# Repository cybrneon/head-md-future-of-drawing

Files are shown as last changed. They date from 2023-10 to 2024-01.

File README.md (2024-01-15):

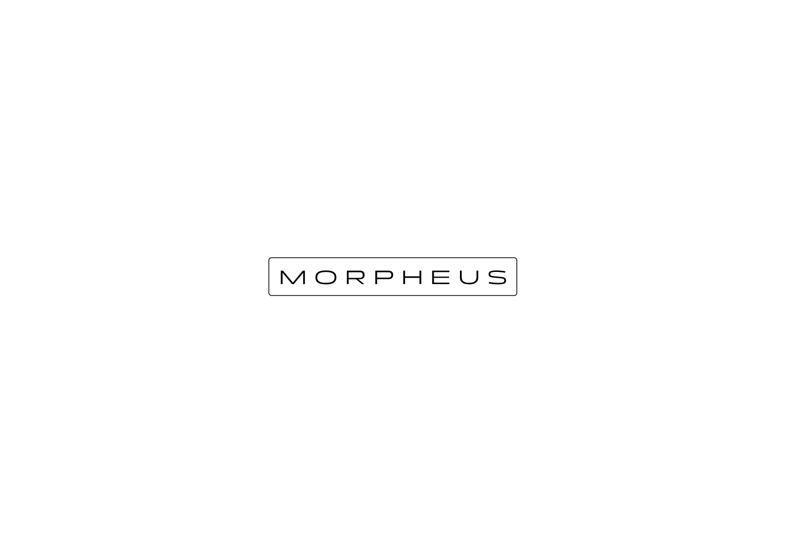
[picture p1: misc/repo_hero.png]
Project Morpheus


# Project Morpheus
Introducing, Morpheus. Your new, AI-enabled, narrator and guide to a new world of unlimited possibilities.

This project is the result of a semester workshop on drawing at the Master [Media Design](https://www.hesge.ch/head/en/programs-research/master-arts-media-design), [HEAD-Genève](https://www.hesge.ch/head/formations-recherche/master-en-media-design) in collaboration with [Caran D'Ache](https://www.carandache.com/ch/en)
<br>
With Alexia Mathieu, Douglas Edric Stanley, Laure Krayenbühl, Pierre Rossel and Pablo Bellon.

## Keywords
drawing, writing, drawing tools, writing tools, artificial intelligence, interaction design, storytelling objects, novel interactions, playable objects

### [**Process**](/process/)
Checkout the whole process for the project from the early beginnings to the end.

### [**Form**](/form/)
Design of the object's shape with 3d files.

### [**Electronics**](/electronics/)
Beep beep boo boo boop with Fritzing schematics.

### [**Presentations**](/presentations/)
Presentations from the concept to the final presentation.

### [**Software**](/software/)
Morpheus's Python script and files + tutorial on how to set up RPI.

### [**Story**](/story/)
One Story, its parameters and AI Output.

## Thanks
Thanks to the teacher's dedication, help and motivation throughout the project.

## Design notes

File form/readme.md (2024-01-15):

# Form

> [!INFO]
> Last Update: 2023-12-27 at 6:50pm

## 3D model
Here you will find my [Fusion 360 file.](/form/source/projectmorpheus_id.f3d)
And my STLs [here](/form/source/print).

## Snapshots
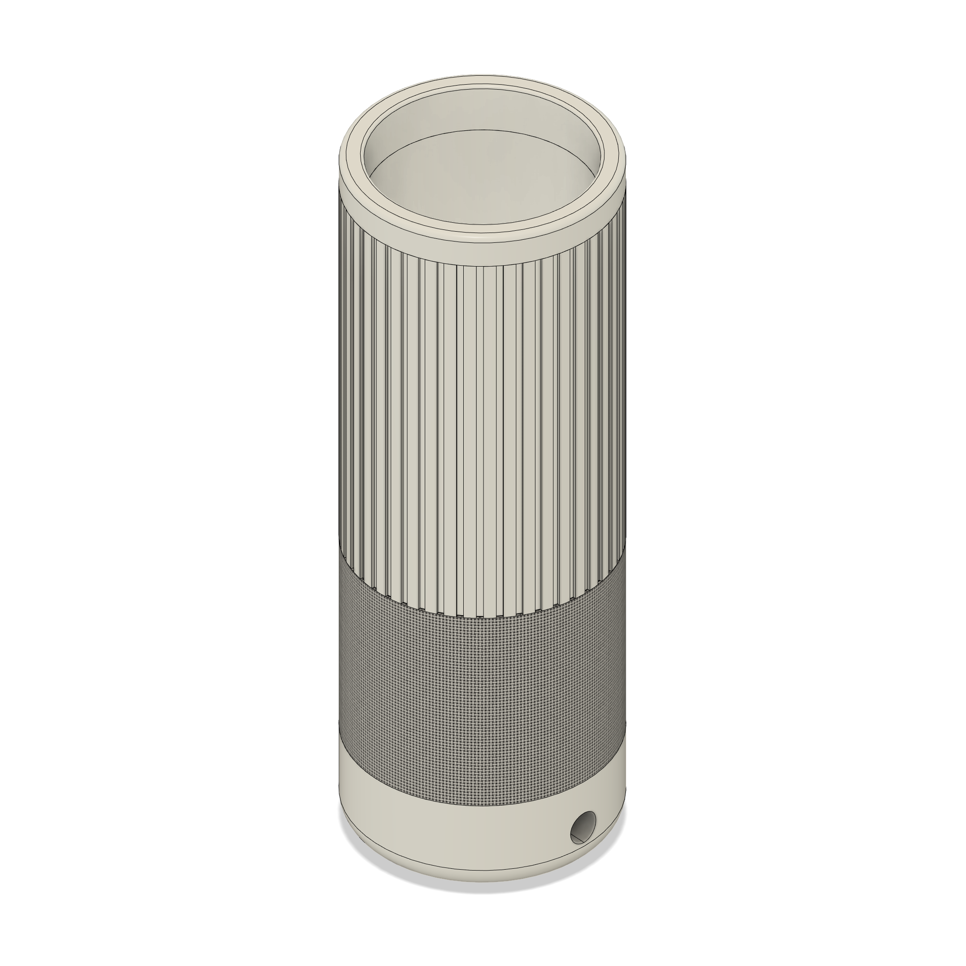
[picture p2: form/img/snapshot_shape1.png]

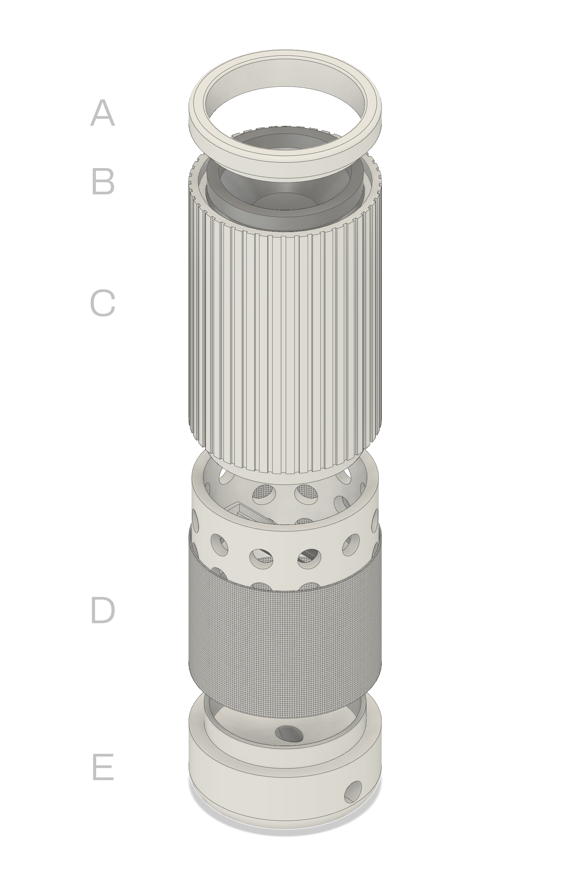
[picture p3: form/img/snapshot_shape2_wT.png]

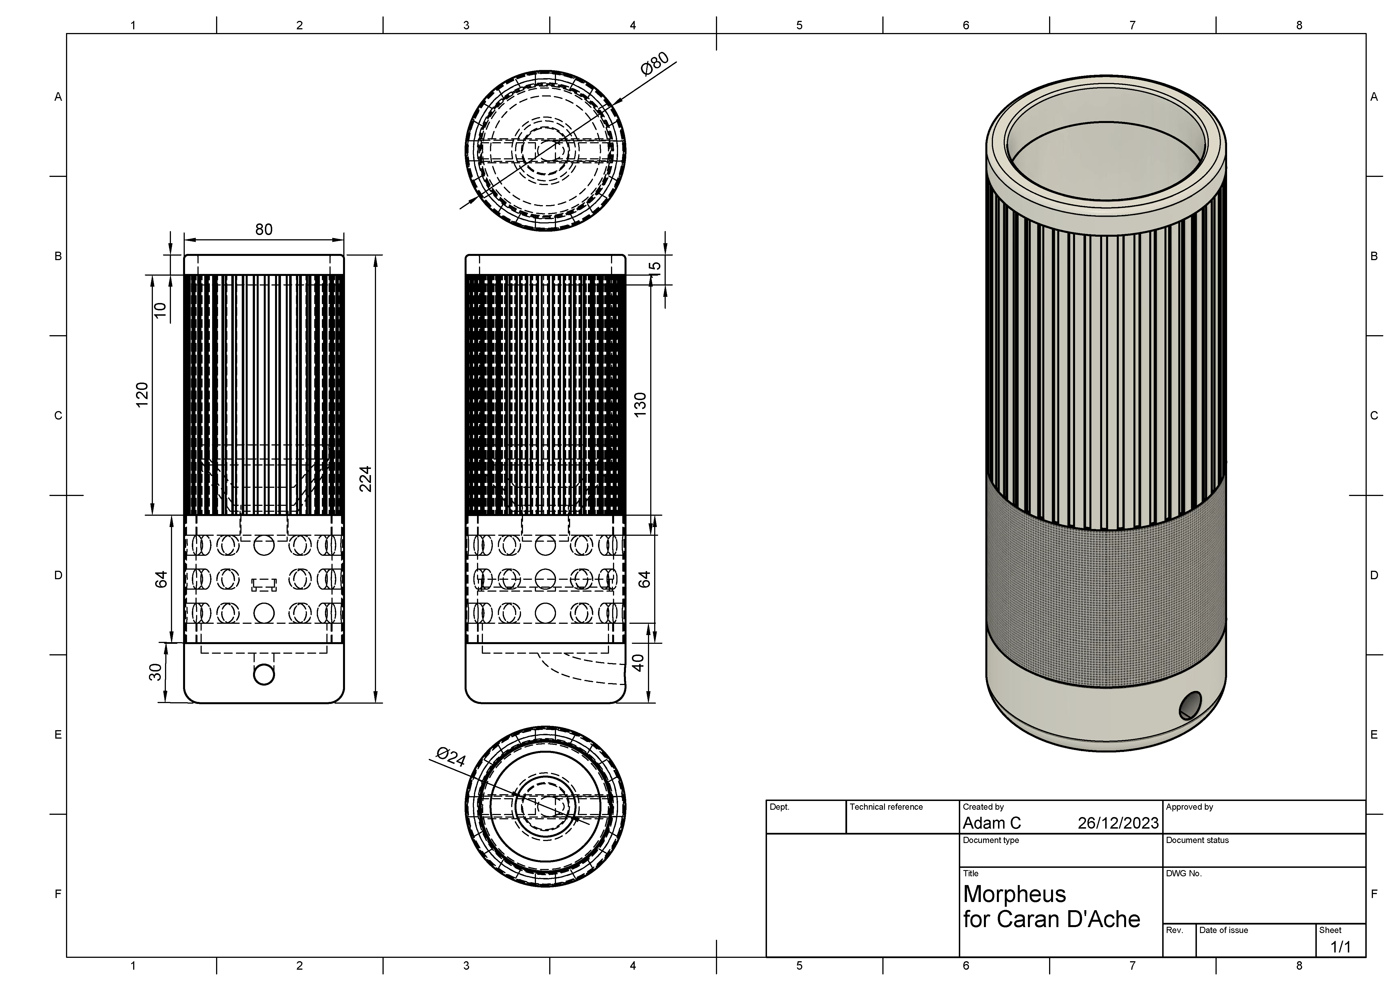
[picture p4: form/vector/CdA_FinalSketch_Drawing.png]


## Parts
A. Top Cover
<br>
B. Pen Trap Detector
<br>
C. Pen Holder Cylinder
<br>
D. Speaker Cage (Hidden, covered by fabrics)
<br>
E. Support Base

## Materials used
3D Printing for all parts (Atelier Prototypage).
<br>
The speaker cage is covered by fabrics (Linen).

## Dimensions
<b>The size of the whole structure is 220×80×80mm (H × W × L) </b>
<br>
A. 10 × 80 × 80 mm
<br>
C. 120 × 80 × 80 mm
<br>
D. 60 × 80 × 80 mm
<br>
E. 30 × 80 × 80 mm

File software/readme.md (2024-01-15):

# Software

## What I'm doing
I'm playing a sound each time the pen is removed from the pen holder, and stopping the sounds when the pen is inserted in the pen holder.

## Tutorial

### 1. Setting up the RP
This setup applies if you're flashing and connecting from Windows. MacOS should be slightly different.
#### Installing Rapberry Pi OS (64Bits), released on the 2023-12-05 (5dec23)
Flashing on a SD card, and setting up settings for automatic wifi connection and SSH.

When the RP is booting, connect by SSH from the Terminal to enable VNC that will allow connecting to the RP wirelessly without a screen connected.
<br>
`ssh pi@raspberrypi.local`
<br>
enter the password you set when flashing the SD card.
The RP will give you a welcome message and be ready for commands. Then type:
<br>
`sudo raspi-config`
<br>
First select Interface > VNC > Enable.
<br>
Go back with ESC and select Display Options > VNC Resolution > And set a resulution for the display you'll see in the VNC Viewer App you'll install on your computer. I recommend `1280x720`, `1280x1024` or `1200x1600`.

Now, you can use VNC Viewer on your computer to connect to the RP by connecting to the address `raspberrypi`.

> Attention!
> Your computer and the RP has to be on the same Wi-Fi network.

> Attention!
> VNC Viewer has some unexpected behavior. VNC never worked all the time.
><br>
> If VNC doesn't connect or if it takes too much time, close the app and relaunch it again. If it's still not working, keep doing that.

When booting into desktop, apply system updates before doing anything. (you can do these in SSH, on the Terminal)
<br>
`sudo apt-get update`
<br>
`sudo apt-get install`
<br>
`sudo apt-get upgrade`

You have now sucessfully set up the Raspberry Pi!

#### Installing Software
To install the Adafruit speaker bonnet, I type this into the Terminal to install i2s amplifier:
`curl -sS https://raw.githubusercontent.com/adafruit/Raspberry-Pi-Installer-Scripts/master/i2samp.sh | bash`

[GitHub Source](https://github.com/adafruit/Raspberry-Pi-Installer-Scripts)

Do this one time, reboot. Do it a second time, it will ask to test the speakers and type Yes.
If there's no sound, keep following the setup and reboot again.
Now, you should open up the terminal (on the desktop, or SSH) and type:
<br>
`sudo raspi-config`
<br>
Go to System > Default Audio > and select the new device that should be called "hi-fi-berry" or something like that.

If there's no sound when you play something, go to the top bar of the Desktop UI, on the Sound icon, right click and select the new device.

Normally, it should work now.

You can also check in the terminal:
`alsamixer`
<br>
It will open the system sound mixer. Press F6 and select the new device.

### 2. Enabling autostart
To enable a python script automatically at startup, you need to create a folder inside of home/pi/.config called `autostart`, where you'll put a file called `something.desktop` (the something can be replaced by what you want to call the file).

Open the file, and paste this inside:

[Desktop Entry]
<br>
Encoding=UTF-8
<br>
Type=Application
<br>
Name=<Something>
<br>
Comment=
<br>
Exec= python /home/pi/desktop/Morpheus/morpheus.py (here you can put the link to your python exec)
<br>
StartupNotify=false
<br>
Terminal=True
<br>
Hidden=False

And it's done! Now reboot and the python program should autostart.

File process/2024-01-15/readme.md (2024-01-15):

# Quick Talk with Douglas monday morning

So, about that interaction. Instead of repeating the whole mp3, why not cut multiple mp3s and when the user stops the experience, they can then resume from a checkpoint, without relistening from the very start.

I currently can't seem to find a way to do that in Python, but I have the script playing file after file.

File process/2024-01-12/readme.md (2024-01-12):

# Progress of the day
## Tasks

### Done
- ~~Find a better solution for the pen detection, putting weight into the top of the pen like lead (plomb), and not using ugly wood.~~ -> I solved this by putting my Caran d'Ache pen, it's not a pencil. I'll keep testing if I put multiple pens for example. 
- ~~Story generation with AI.~~ I generated one story and edited it in my DAW, also added sound effects as it was something people told me (during test days) would have immersed them more.
- ~~Software corrections and boot setup.~~ Set script to autorun at boot.
- ~~Back up sd card!~~ Done.
- ~~Label the cables so I can recognize which cable is which.~~ Done.

### What's remaining
- Finding how to hide the RPI.
- Presentation and finish Project Documentation

## Other stuff
I also put a startup and shutdown sound to the RPI so I now if everything's going according to plan, but they don't work. Probably because the RPI initializes the GPIO at the end of the boot sequence? compared to the 3.5mm jack or HDMI.

Also, the autorun for my python script runs and then cuts quickly. I need to remove and put the pen again for it to work. But that's fine for the presentation.

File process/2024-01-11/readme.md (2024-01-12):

#  Progress of the day

The software is done. I just need to work on the story and push it through Text-To-Speech.

The presentation is almost done, I only need images of the device and small refinements here and there.

## Check-up with Douglas at noon
I'm on the right track, here's what's remaining to do.
- Find a better solution for the pen detection, putting weight into the top of the pen like lead (plomb), and not using ugly wood.
- Story generation with AI.
- Software corrections and boot setup.
- Finding how to hide the RPI.
- Presentation and finish Project Documentation
- Back up sd card!
- Label the cables so I can recognize which cable is which.

## Other
Here are settings for Google's TTS:

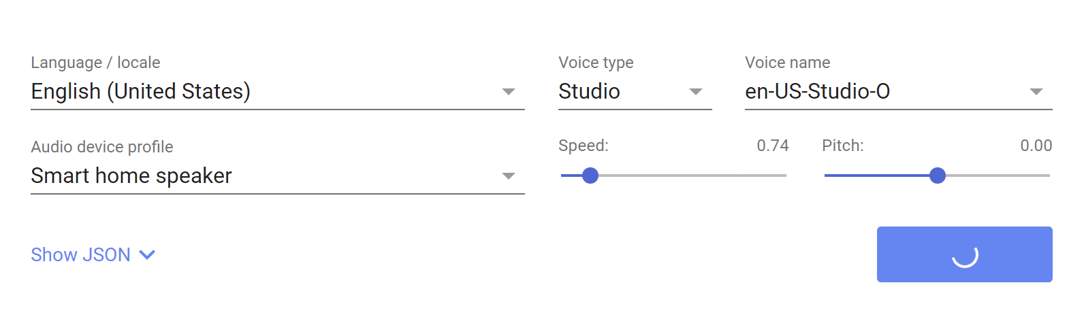
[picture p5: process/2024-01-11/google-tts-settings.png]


I then go to the browser's Dev Tools > Get to the Network Tab > filter "proxy" and look for "proxy texttospeech" > reveal source > and get the JSON. Most important is the "audioContent" part, that I then put in a Base64 to mp3 decoder (https://www.ipvoid.com/base64-to-mp3/), or do it local on my machine!

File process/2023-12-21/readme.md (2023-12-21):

# Today's Work

## 3D Print
My 3d print was done and it was so nice to see the final result.

## Talking with Laure
The comments from yesterday still apply! Now, for the micro-switch to be positionned inside of the shape and for the pencil to activate it, it needs a base or something that presses the micro-switch enough.

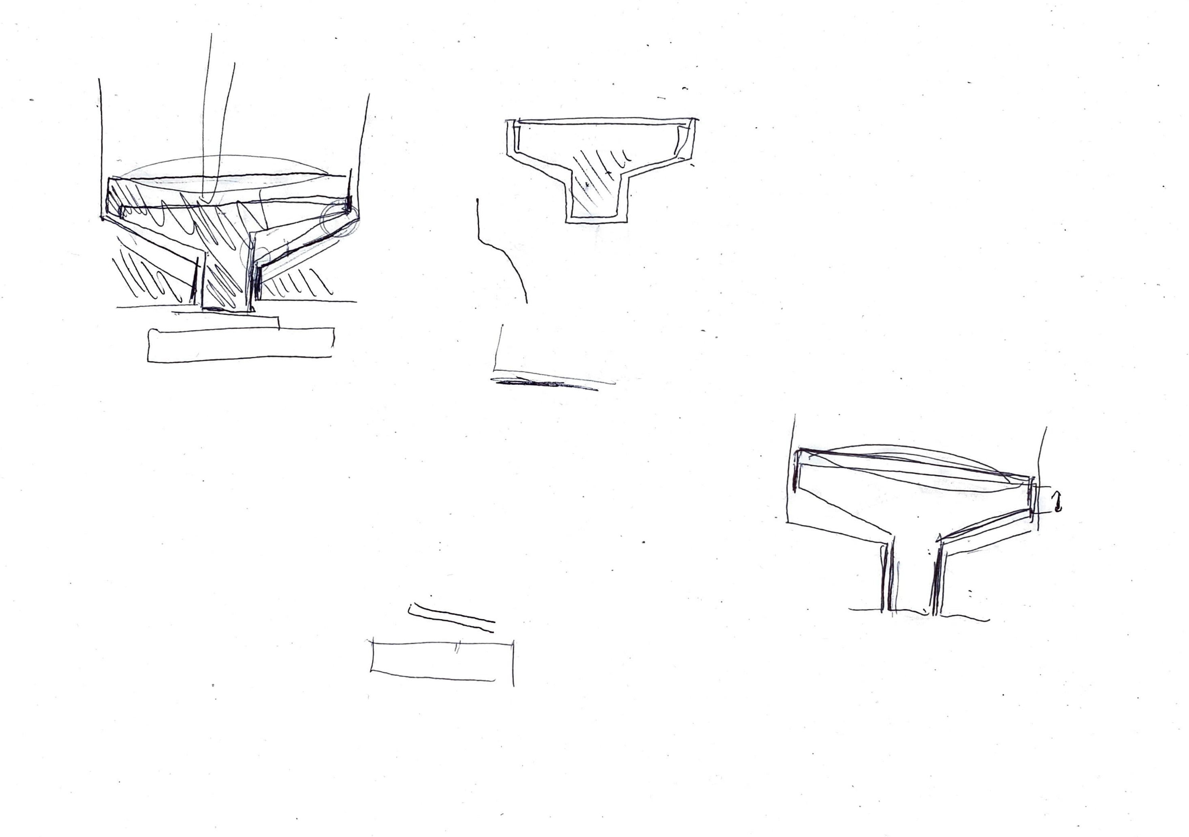
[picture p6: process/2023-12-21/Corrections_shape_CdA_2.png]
Sketch


## Talking with Douglas
We talked alot and deeply into my project. Looking at how I can make my project come to life.

### Software
#### 1st Step
<b>Making a simple python program that detects the switch and plays mp3s.</b>
<br>
Using pull-ups, I don't need a resistor. So one cable goes into the GPIO 4 pin, and the other goes to the GND. The electrical current will go from the pin number 4, stop, and only go to the ground when the micro-switch is pressed.
<br>
<b>Tools:</b> python-vlc (included).

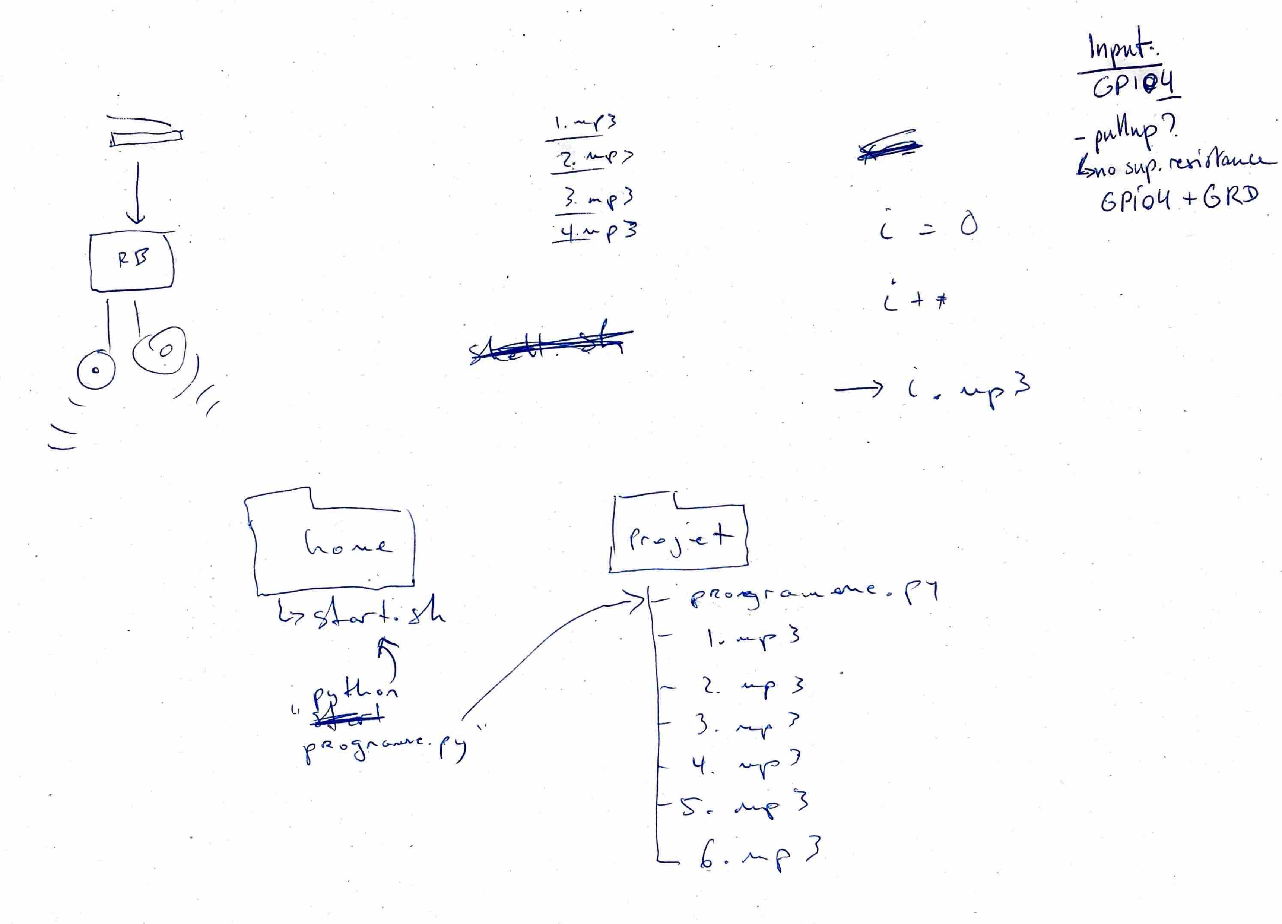
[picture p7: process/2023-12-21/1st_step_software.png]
1st step


`Code will go here when I'll boot up the RPI next time to save my progress`

#### 2nd Step
<b>Making a script that communicates with an API to generate text, generate text-to-speech and play it back on the RPI.</b>
<br>
This one is the most trickiest one, but is not impossible.
<br>
<b>Tools:</b> Bard, Google TTS, Piper, Hugginface, ...

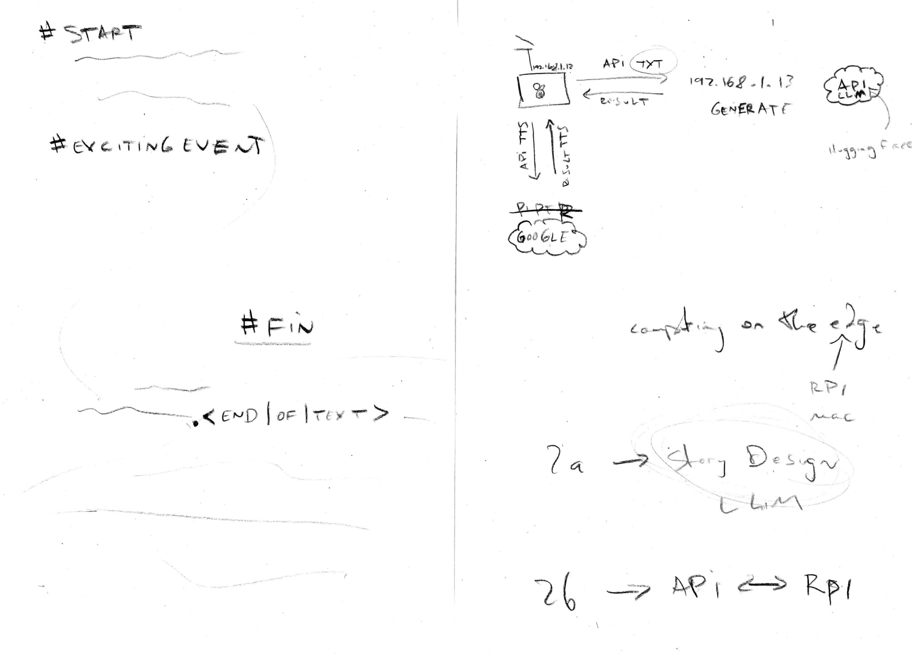
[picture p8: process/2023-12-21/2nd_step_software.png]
2nd step


### Story
And finaly, the most important thing in my project. Douglas compared storytelling to a campfire story, a comparison I simply find soooo beautiful and true.
To use it and let the AI _délirer_ with what I'll give it, I need to do sections like #Start, #EveningEvent, #End, ...

## Getting the textiles for the speaker wrap
So I went to IKEA, even though it was my day off, but I went home with nice textile huts from curtains. From thin to thick, I took 4 colors.

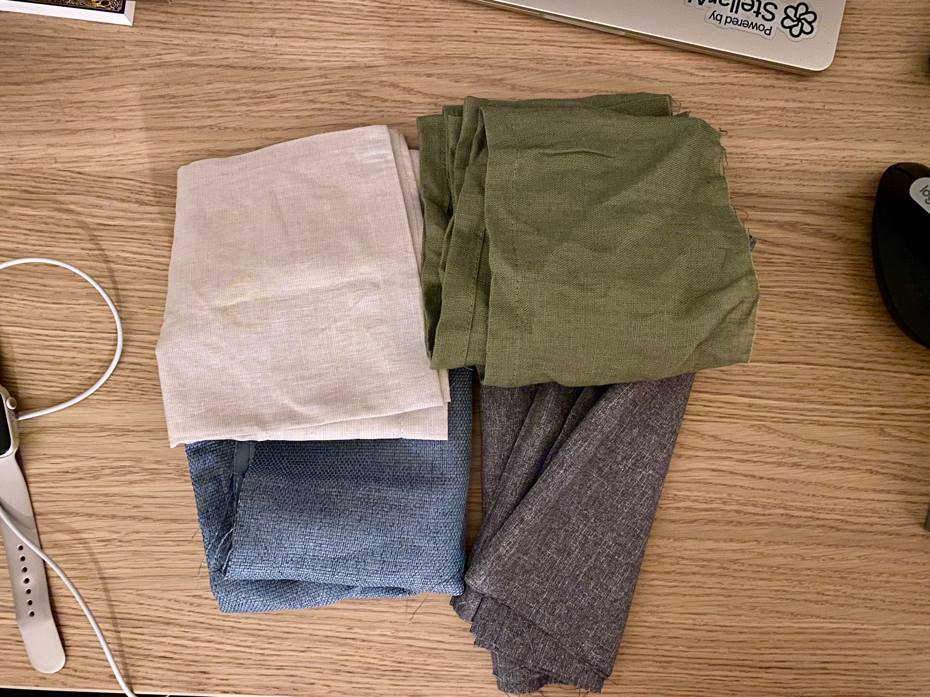
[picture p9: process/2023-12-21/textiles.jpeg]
Textiles


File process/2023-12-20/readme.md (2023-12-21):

# Talking about the shape with Laure

## Corrections to do to my shape
We talked about the top part, where I should do a staircase thing.
We talked about the speaker cylinder and how it sticks to the other parts with the textile.
We also talked about how the textile will fit and how it will be folded on the inside.

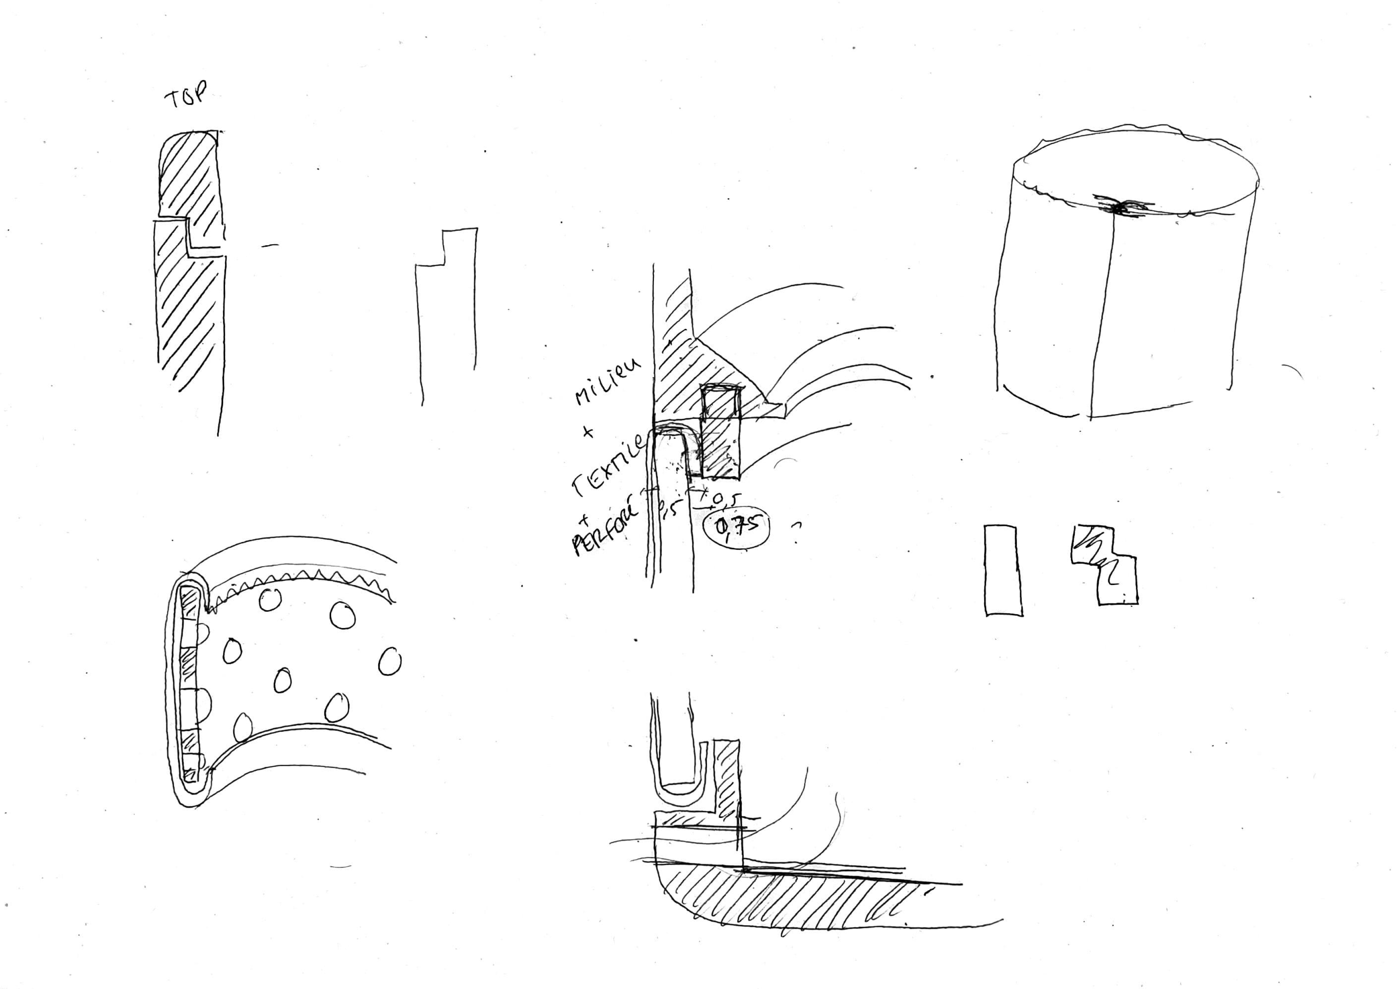
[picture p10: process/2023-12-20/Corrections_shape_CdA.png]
Corrections for the shape


## At the same time
- I booked a 3d print at the prototyping atelier for the 8th of Jan 24.
- I launched a print of a low quality print at the Pool Numérique (I should get it the day after).
- I'm trying to make the RPI function with the speaker bonnet and the speakers. Nothing works and I don't know why. I checked blogs, online, videos and lots of people seem to have the same problem without a real fix...

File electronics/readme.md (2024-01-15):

# Electronics

In this folder, you'll find the tutorials with Pierre, the experimentations, and the final result.

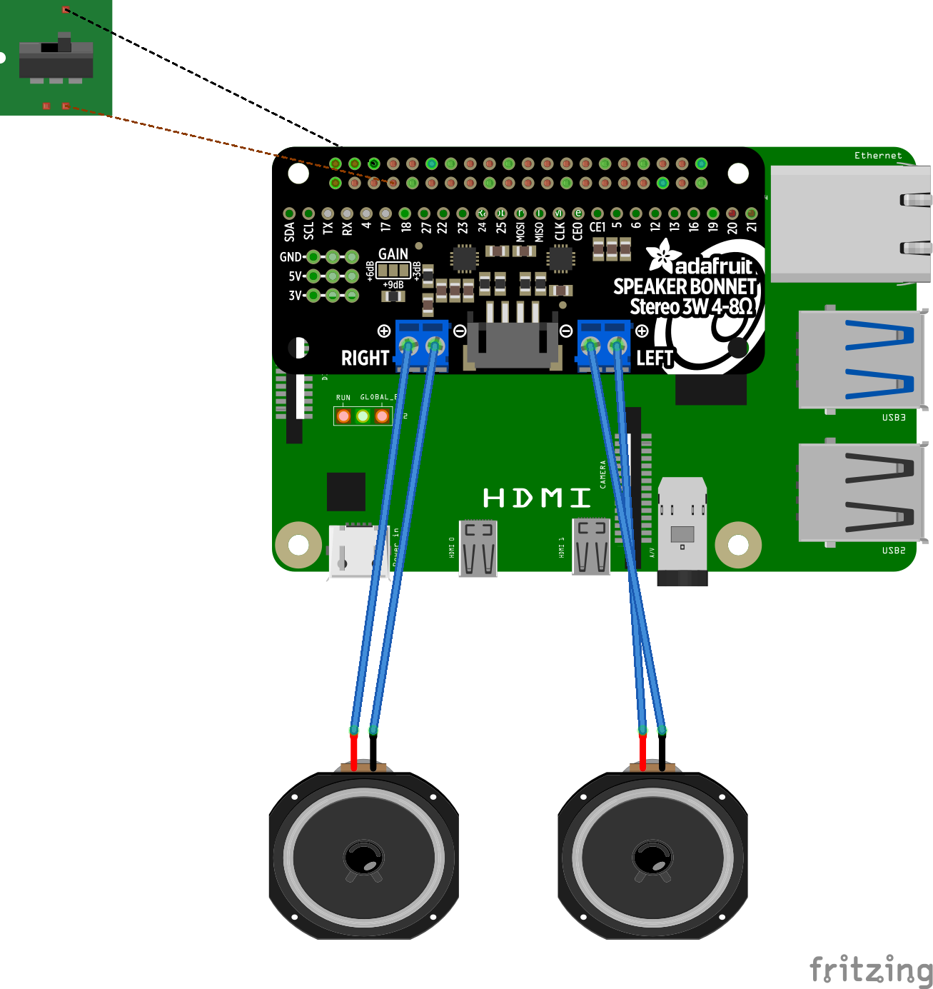
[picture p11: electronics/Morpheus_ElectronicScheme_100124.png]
Project's Electronics

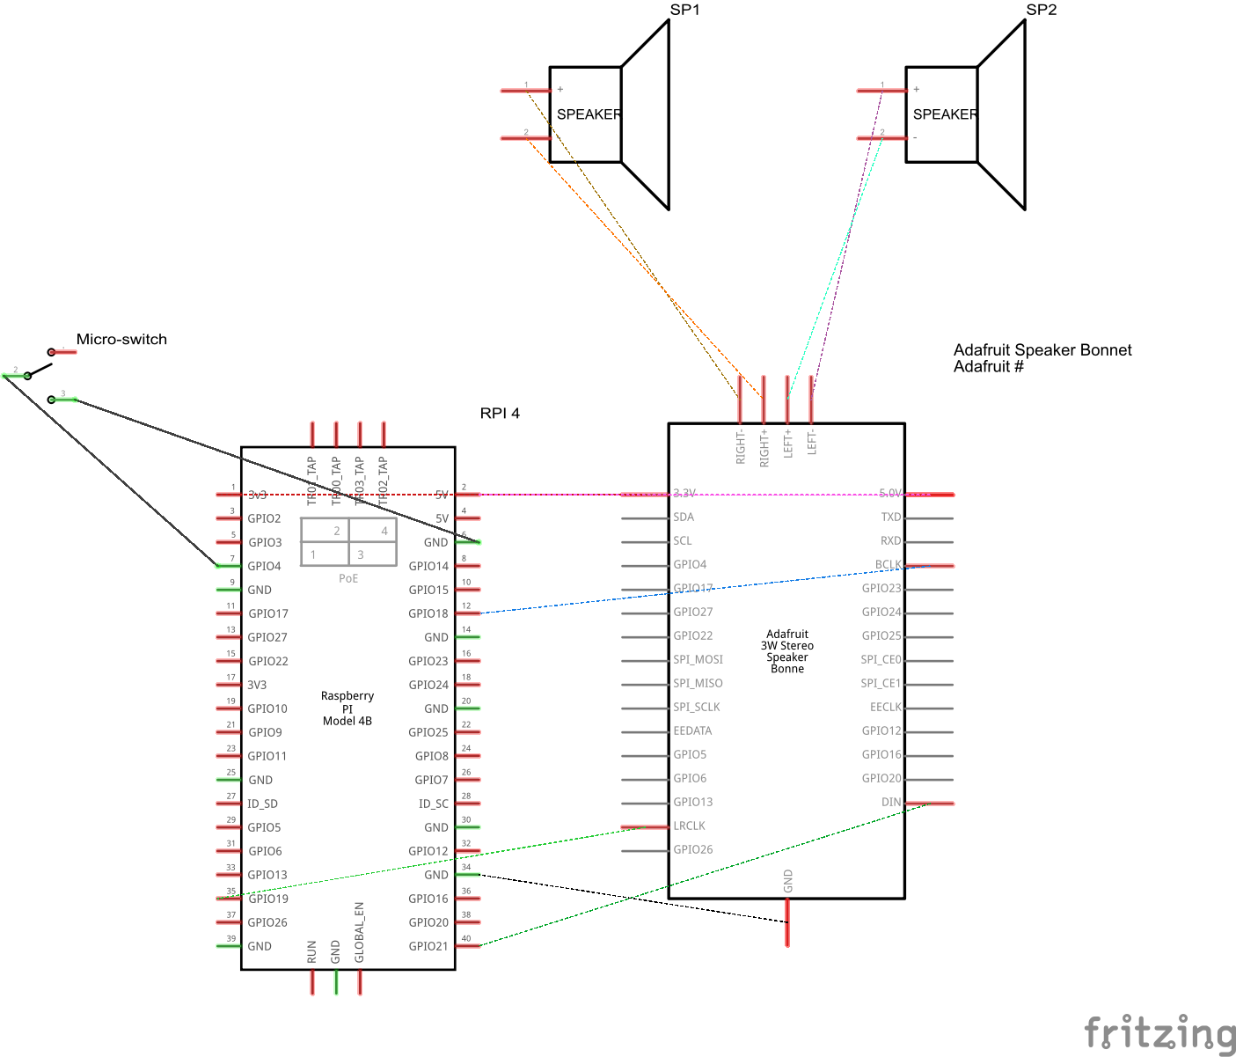
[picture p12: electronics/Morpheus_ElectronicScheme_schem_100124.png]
Project's Electronics


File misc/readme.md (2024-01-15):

Nothing to see here lol.

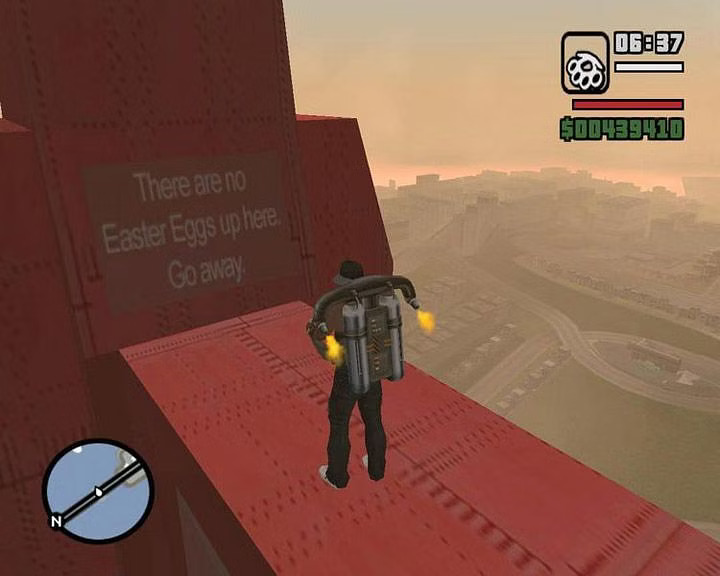
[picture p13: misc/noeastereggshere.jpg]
Why are you checking the markdown?? Where is trust??


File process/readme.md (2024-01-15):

# The Process

> <em> "Trust the process" </em> - Random Person, Unknown Date

# Table of Contents
Take a look at my long process here, where I share everything I did from the beginning to the end.

## Phase 1
### [- First Field Research and Interviews (2023-10-19_20)](/process/2023-10-19_20)
### [- Performative card game & Paper Prototypes (2023-10-25)](/process/2023-10-25/)
### [- Paper Prototypes Experimentation (2023-10-26)](/process/2023-10-26/)
### [- First Concept and Prototype (2023-10-30)](/process/2023-10-30/)

## Phase 2
### [- Interviews and Interaction Testing (2023-11-01)](/process/2023-11-01/)
### [- Working on Naration (2023-11-02)](/process/2023-11-02/)
### [- Preping for Monday (2023-11-12)](/process/2023-11-12/)

## Phase 3
### [- Defining an Identity for the physical object (2023-11-13)](/process/2023-11-13/)
### [- Defining an Identity for the physical object PART 2 (2023-11-14)](/process/2023-11-14/)
### [- 1 Day Before Concept Presentation (2023-11-15)](/process/2023-11-15/)

## Phase 4
### [- The Day (2023-11-16)](/process/2023-11-16/)
### [- Electronics Experiments](/process/2023-11-30/)
### [- Thinking Industrial Design and Electronics](/process/2023-12-04/)
### [- 🔁 Mini-Reset with Douglas](/process/2023-12-07/)
### [- Progress of the day](/process/2023-12-12/)
### [- Test Day Prep](/process/2023-12-13/)
### [- Test Day!!!!](/process/2023-12-14/)

## Phase 5
### [- Talking shape with Laure](/process/2023-12-20/)
### [- 3D print and Textiles](/process/2023-12-21/)
### [- Diving Back into the Project](/process/2024-01-08/)
### [- Software and Check-up with Douglas](/process/2024-01-11/)
### [- Last tasks for the end of the project](/process/2024-01-12/)
### [- Quick Talk with Douglas monday morning](/process/2024-01-15/)
### [- -1 Day before Final Presentation](/process/2024-01-16/)

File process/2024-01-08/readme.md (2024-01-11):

# Diving back into the project
I just came back yesterday afternoon from a week in the sun at 20 degrees, to the lovely swiss weather of 0 to -2 degrees with strong winds.

Diving back to the project is going to be slow, but fine.

## 3D print status
Fred launched the official and final print for my revised shapes. I should get it at the end of the day. Update: Two pieces didn't finish yet, so I'll get them on Tuesday.

## The Code for the program
```
# MORPHEUS SOFTWARE 1.0
# CYBRNEON SOFTWARE 2024

import RPi.GPIO as GPIO
import random
import vlc		#VLC Media Player library
sounds = vlc.MediaPlayer("/home/pi/Desktop/Morpheus/audio/test2.mp3")		#Locating the sound and setting it as sounds
from time import sleep		# this lets us have a time delay (see line 15)  
GPIO.setmode(GPIO.BCM)		# set up BCM GPIO numbering  
GPIO.setup(4, GPIO.IN, pull_up_down=GPIO.PUD_UP)		# set GPIO4 as input (button)
  
try:  
    while True:            	#similar to Loop
        if GPIO.input(4): 	# if port 4 == 1
            print ("GPIO 4 is 1/HIGH/True - Sound Playing")
            sounds.play()
        else:  
            print ("GPIO 4 is 0/LOW/False - Sound Stopped")
            sounds.stop()
        sleep(0.1)         # wait 0.1 seconds  
        
except KeyboardInterrupt: # stop the program with Ctrl + C
    pass
  
finally:                   # this block will run no matter how the try block exits  
    GPIO.cleanup()
```

## Thinking about the final presentation
For Thursday 11 Jan, at 15h, first draft of project documentation PDF.

On Monday 15 Jan, 17h final version of project documentation PDF.

And a big yay! I can finally present my project the way I want with a custom presentation (on top of the project documentation that will be given).

## Also thinking of the AI part
I'm trying to see how I can do what I wanted to do, easily without too much hassle.

Here's a link I used to encode Base64 to mp3 for tests I got with Google's TTS.
https://www.ipvoid.com/base64-to-mp3/

## And finally
Because I'm sick, I'm missing a day to go see my doctor about a quite serious issue.
But I'll still work a bit.

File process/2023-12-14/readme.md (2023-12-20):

# TEST DAY !!!!

Today, I tested my stories to multiple three people and got interesting insights.

## Morning
Even tho it wasn't the best conditions (calm & alone), I tested on Narges. Luka said that it gave him the desire to draw even tho he didn't try it and just listened to me narrating the stories.

They mentioned pausing the story, give time to draw and not miss the story.

On the second story, Narges found it too complicated because there were too much info. But at the same time, this version gives much more freedom, and you can care more about the story. So she prefers the second one! She loves it.

Luka mentionned testing on children.

Maybe I can have a simple summary at the beginning, slower on the story to introduce people and give them time before diving into more complex stuff?

#### First Story Output
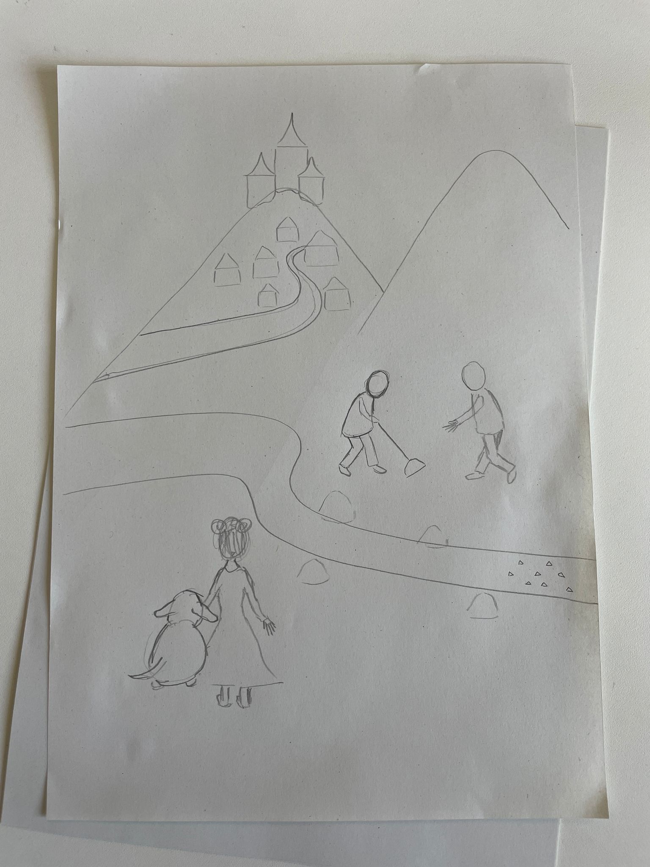
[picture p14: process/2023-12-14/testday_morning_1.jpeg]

#### Second Story Output
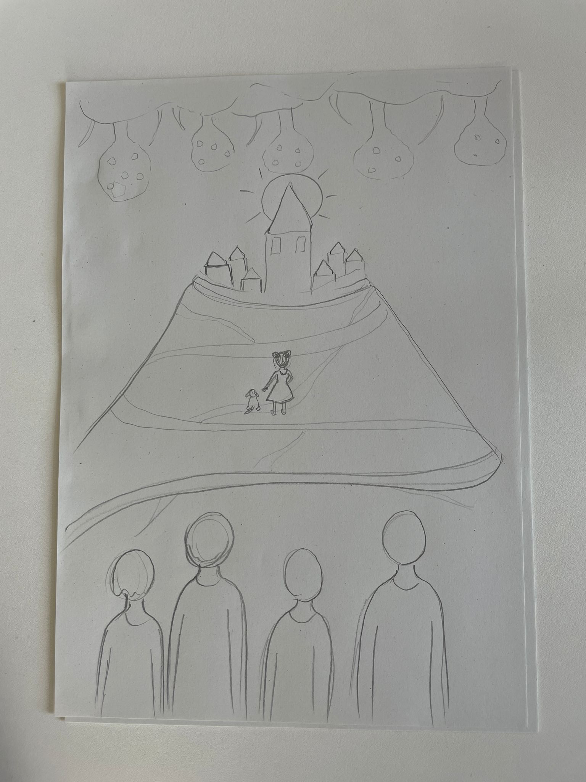
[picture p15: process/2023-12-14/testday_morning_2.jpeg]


## Afternoon
First person of the afternoon, Flore, said it was too fast and surprisingly, and unexpectedly, stopped the experience on the first story.

Flore said it went too fast, and maybe I should think of having multiple modes. One simple, another more detailed? She also thought about having sounds or music? for example when I begin with the river you can hear water sounds.

Jonas also mentionned having a feather at the top of the pen or something to make it more majestic and more dynamic.

Elie on the other hand, loved the experience and the way I narrated it. He talked about the fact that when he was drawing, he had trouble changing views (mountains to lakeside for ex.). He mentionned that i needed to be careful with the camera. He couldn't do a scene because he didn't have space at the bottom of the page so he put it at the top.

He also told me that he would have enjoyed something without sense, something abstract that plays with the subconscious and can help with the creation. He talked of stuff that doesn't make sense like shapes and colors mixed with the story. (I tought this could go well with AI).

He also said that using text to speech could leave the humanity of my voice behind. The second text also had much more atmosphere compared to the first one.

One last note, having two modes is not a bad idea. Like a direct mode that speaks and narrates a story. And another Subconscient mode that would mix with different and not related stuff (délirer!).

#### First Story Output
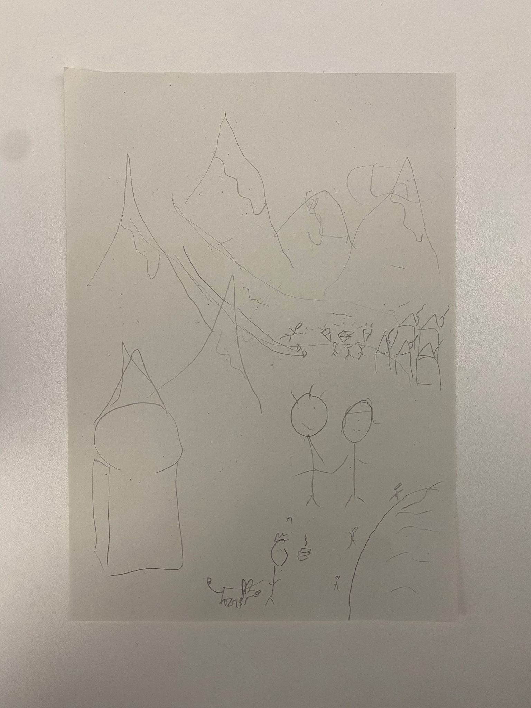
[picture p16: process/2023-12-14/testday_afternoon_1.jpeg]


#### Second Story Output
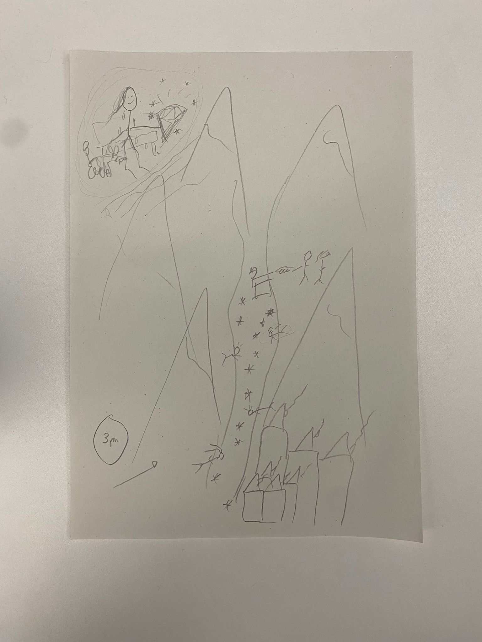
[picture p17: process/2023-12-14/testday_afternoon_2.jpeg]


## Quick Talk with Laure before the end of the day
We quickly talked about the shape realization in metal.
But also, about the aluminium spray I wanted to do, to mimic real aluminium or metal.
Laure gave me a big no, because it doesn't end up like you want it to end up, soooo I'll obey and trust Laure on that 🫡.

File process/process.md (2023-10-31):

# The Process

## Goal
I started researching the subject of everyday stress, stress in general, chronic stress, its reaction on the body. I also red people's questions and answers on Reddit for when people ask about how can they manage stress, in which people usually detail their stress relief methods to others.
Then, I looked at alternative drawing techniques, to tackle everyday stress.

So here are some drawing techniques and how they help. Some different and more expressive with the body than others.

## Unusual Drawing Experiences
### Unusual Drawing Experiences
- Drawing with your hands in the air
- Drawing with a pen in your elbow
- Collaborative drawing (with a friend, taking turns to draw)
- Mouth painting (holding a pen in the mouth and drawing)
- String Art, attaching a string to the pen and controlling the drawing
- Foot drawing, using feets to draw on a large canvas

### Mindful Meditation Drawing:
- Blindfold drawing, drawing a specific object or scene from memory
- Breathing Patterns, syncing inhaling and exhaling with line drawings for ex
- Drawing with your non-dominant hand

## Interview Process
More importantly, I wanted to learn about people's techniques, if they had some. That's why I wrote questions that I then asked to different people in a face-to-face interview.

### First Part of the interview
I asked to rate their daily stress levels, why they were stressed, if they had stress relief techniques, if they were efficient, and if they tried drawing.

### Second Part of the Interview
I then asked to choose one of the drawing techniques I talked about earlier, and it gave lots of really nice results.

### Results
In all of these experiments, people kept saying that they were having fun! At first, I thought people would feel frustrated, but they kept going and adapted to the situation.

What I also find interesting in the interview process, is that when I asked people to rate their daily stress levels, the majority of them gave me a mark out of 10. Even if each person has its own meaning of stress, I was surprised to see how everyone tried to agree on a rating out of 10.

One of the other interessting aspects is the fact that one person talked about having a routine, which is super interessting.

Others talked about how they hate temporary solutions, which is understandable because I don't like them either.

#### Some Images
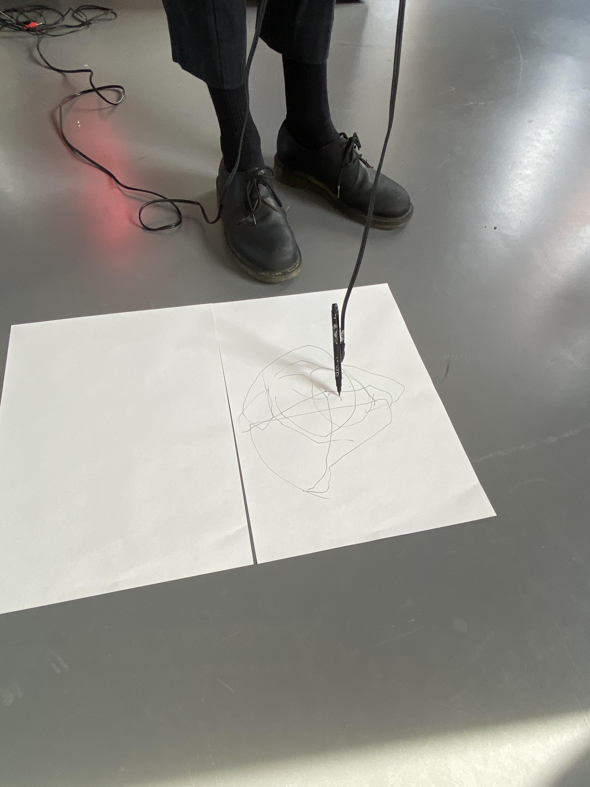
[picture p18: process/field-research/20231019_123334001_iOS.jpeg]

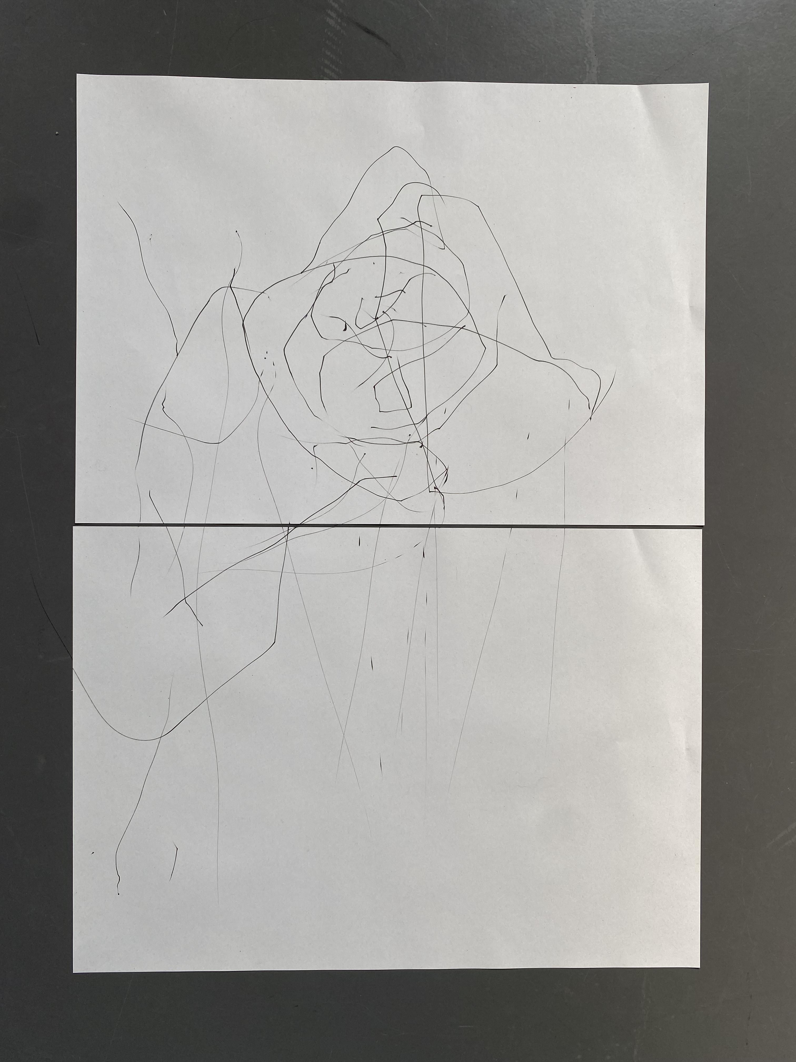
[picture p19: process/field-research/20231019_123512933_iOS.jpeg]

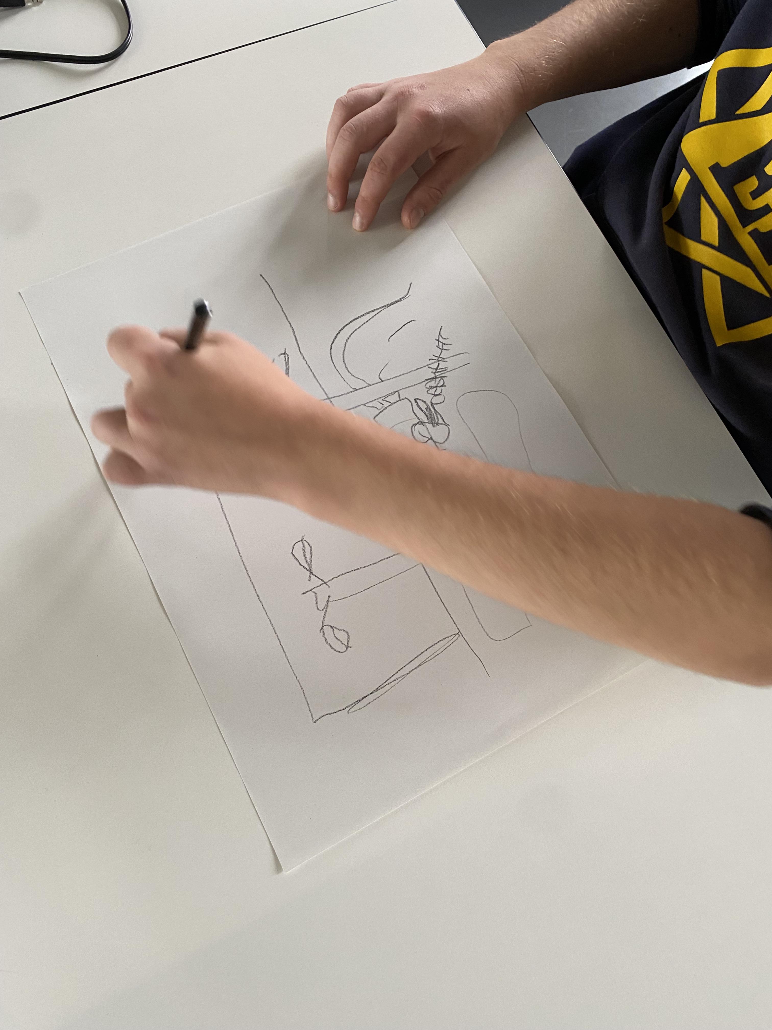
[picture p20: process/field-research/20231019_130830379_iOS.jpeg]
Drawing with your non-dominant hand


## Aftermath of First Insights Presentation
Here are the comments I've gotten from Alexia, Douglas and collegues:
- Keep experimenting!
- The notion of gaming will probably emerge (gamification).
- Spirituality?
- Engaging the whole body?
- Mandalas

# Prototyping? with Paper!
## First Try
At first, I drew the following cards:
- Inks
- Poker Face
- Figuration
- Peltier

I then made an interactive Captcha machine that asks you to draw something on it to confirm you're human, with a voice that asks you why you're drawing things the way you're drawing them and not giving any emotion.

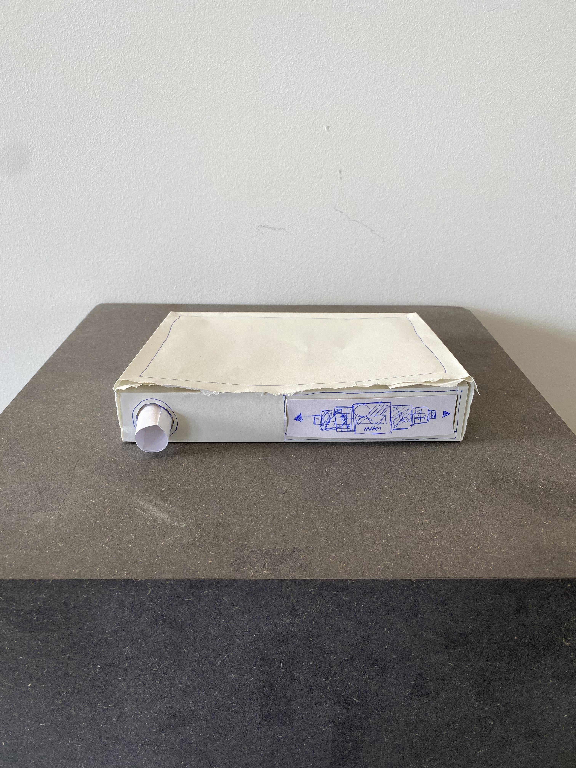
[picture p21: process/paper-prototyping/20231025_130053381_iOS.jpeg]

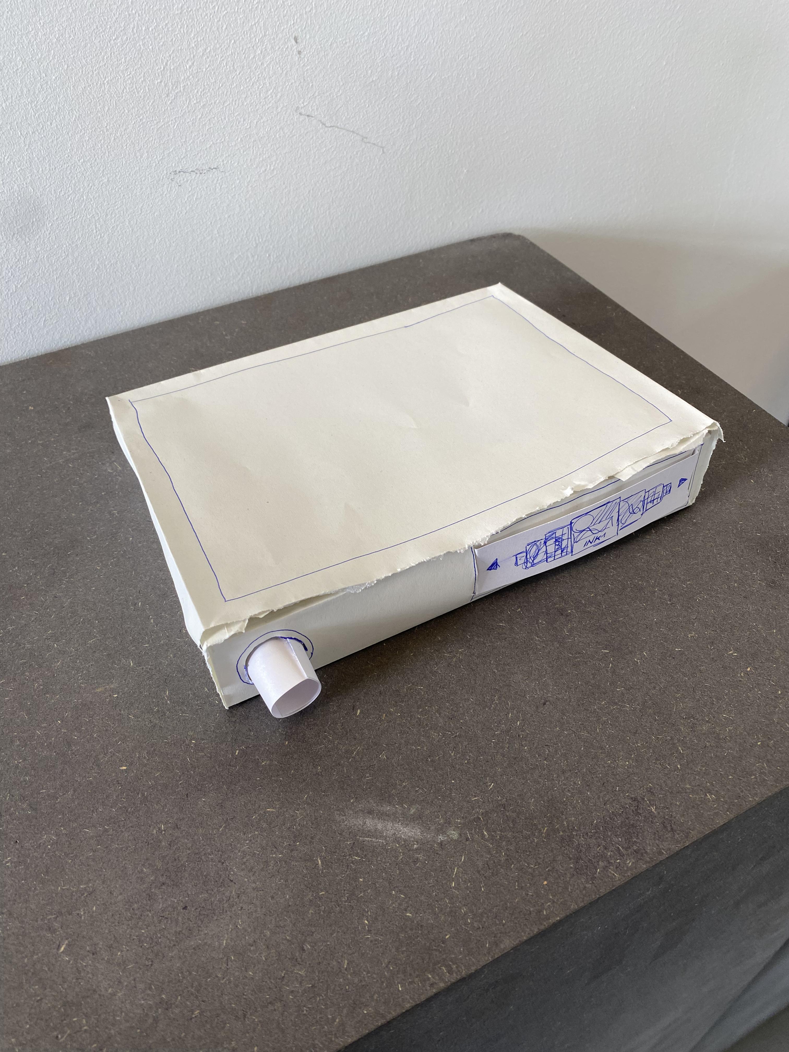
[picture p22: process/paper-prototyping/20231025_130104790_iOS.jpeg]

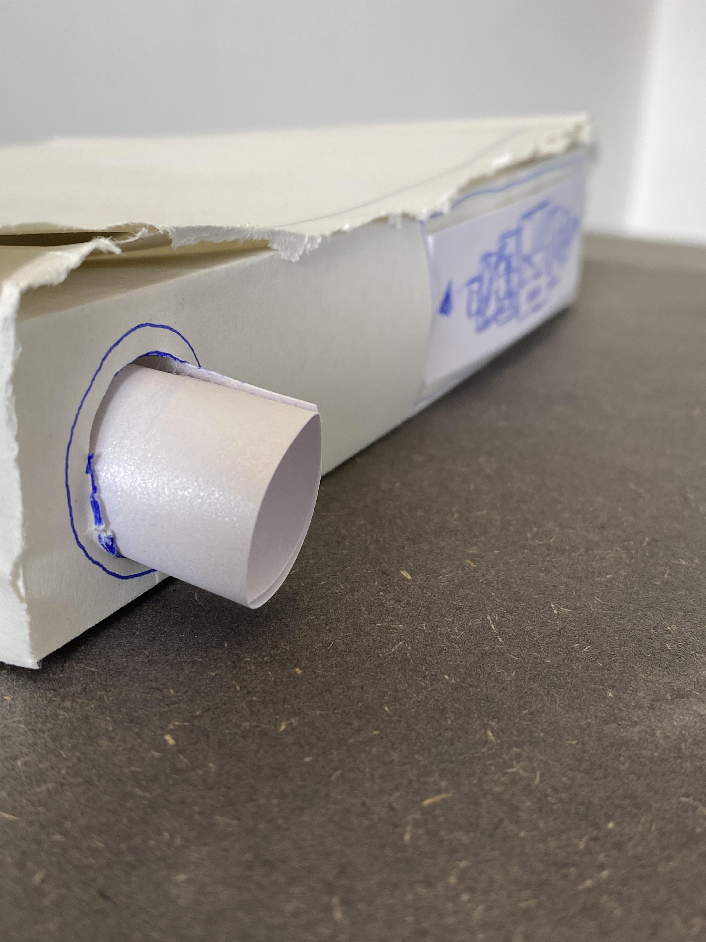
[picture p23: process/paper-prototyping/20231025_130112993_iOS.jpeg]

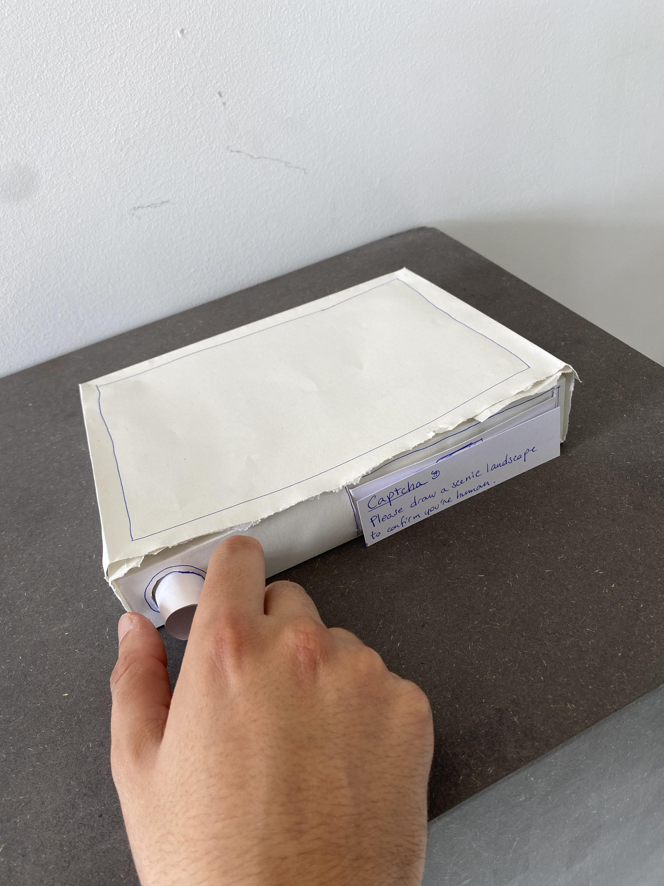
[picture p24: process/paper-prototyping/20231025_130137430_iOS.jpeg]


## Experimentation
We then started to imagine interactions and paper experiments with our subjects. I didn't know how or where to start, so I came back to the cards and drew ones that I then executed into paper prototypes.

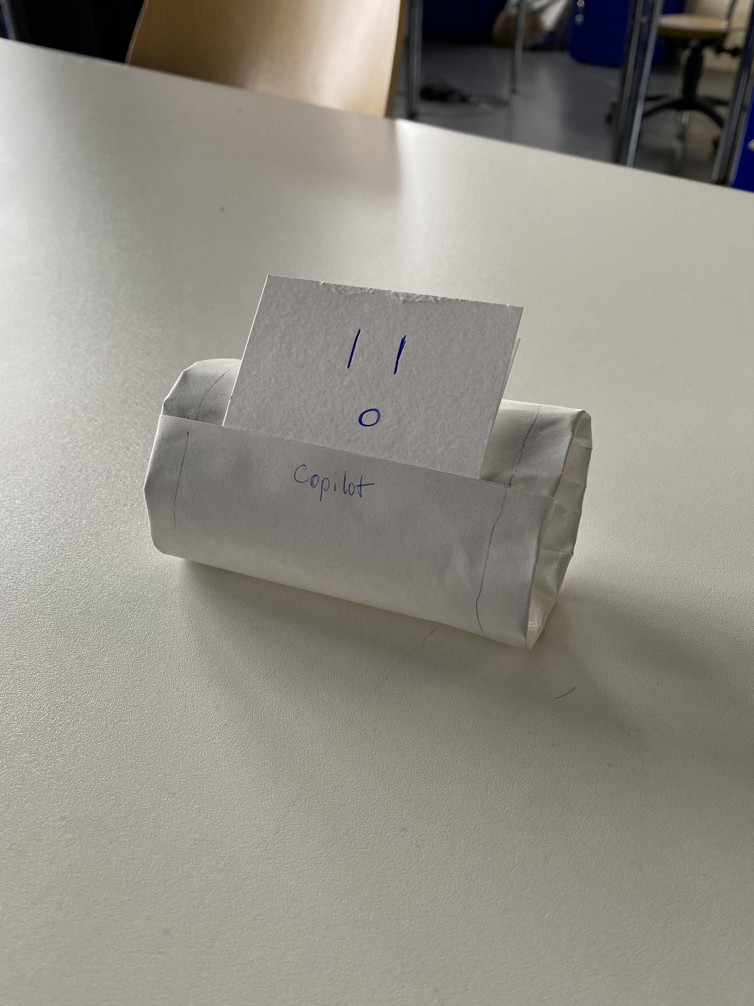
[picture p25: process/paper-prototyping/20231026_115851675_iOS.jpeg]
Little Cute Copilot

Tamagotchi-like Drawing Experience Generator
Drawing Experience Generator Printer

## The First Concept
After the experimentation, it was time to form a first Concept.
Thinking of personalities like Dreamy, A bit too much, Spy, Cheerleader.

## Important Insights
**Routine:** Setting up a routine in the morning or afternoon can be beneficial. Ex: Doing an exercise for 5min in the morning or before bed.
**Stress Level Rating:** Listening to the user's stress level and providing the adequate solution as a drawing experience.
**Positive Comments:** Reassuring the user doint that he's drawing nicely, and maybe provide comments and suggestions (always positive).
**A box:** A small device that can be put in a living room and blend with its space. Ex: Hi-Fi, TV, Clock, Books, Game console, ...
**Interactions:**
- Tap to wake? at the top?
- No smartphone interaction! (no stress in the morning)
- K.I.S.S.
- Was thinking of a sensor attached to a pen, but I think it would be more intereseting to "draw" in the air, with nothing but a sensor (Wii-mote, Kinect). -> Drawing in a space without knowing what you're drawing is pretty interesting. (I have to test that!!!)

## How can the machine function?
1. Turn the machine on (wake it up) by tapping at the top.



2. By that, I communicate the level of stress I'm feeling right now.
3. The machine gives me a prompt to draw with a WHAT and a HOW.
4. With the pen (or the sensor on the finger), the machine understands what I'm drawing and comments on it.
5. After drawing for 3 to 5 minutes, time is up! The machine now shows you the art you've created, and asks you how it went so that it can adapt to you.

## Comments I got from Alexia, Douglas and collegues:
- I need to challenge myself by removing text, and screens (no chatbot-like interactions)
- Be careful not to do too much industrial design. I should focus more on the interactions.
- The routine question is interesting and important. Need to do more research about that.

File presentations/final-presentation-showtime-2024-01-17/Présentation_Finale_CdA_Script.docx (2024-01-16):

Présentation Finale CdA Script

Intro

Welcome.

Have you ever thought about directing your own movies? Have you ever wanted to stimulate your creativity but didn’t know exactly how? What if I told you there is an easy way. What if I told you we could all gather around a campfire and tell each other stories, that we could draw.

Introducing

Introducing, Morpheus. Your new, AI-enabled, narrator and guide to a new world of unlimited possibilities.

Today is the day you’ll cancel your streaming subscriptions, because this is your new Netflix.

And for that, I have a tutorial on how to do so, go to Netflix.com/cancelplan and click on Finish Cancellation.

Now back to my project.

Morpheus is an AI assistant that narrates stories to you while drawing. Each day, you get one episode to draw and each episode can be part of a series. These stories are enabled by chips inside of pens or pencils where each pen has its own story, texture on paper and feeling in the hand.

Where is the AI part you’re gonna ask? Well, each time you turn on Morpheus, it’s going to generate a story based on these pre-defined tags with a scenario, that Morpheus will detail and hallucinate about. So you could get a completely different story each time you go from one episode to the other. Even if you already started a series, what happens next is generated. The ending of the series for example might also be different and that’s where the beauty of Morpheus comes to. You’re not trapped into one linear story, but one that is very much alive.

DEMO

Let me show you how it works. I’m going to take my notebook where I already have a collection of stories.

So, you know pen holders right, you throw pens inside and if you want to use them you just simply lift one and write, pretty simple right??

Morpheus works exactly the same way. Plug it into the wall and voila, it just works.

Let’s start with a story. I’m going to lift my pen and immediately dive into this story that Morpheus will narrate to me. And you can see that even if I’m not drawing perfectly, it’s fine! There’s no need for pressure and it’s not a drawing contest.

I can also invite people to draw with me. Hey ****, do you mind joining me?

And this, now became a group activity, again just like watching TV.

I can either wait for the end of the episode, or just stop it by putting the pen back. There you go.

Conclusion

So we’ve got a beautiful industrial design, a straightforward and simple interaction, and breathtaking ai-generated stories to take you on a journey to another world.

This is a great device, and I’m sure you’ll have fun playing with.

Thank you very much for your attention and I wish you a very good day.

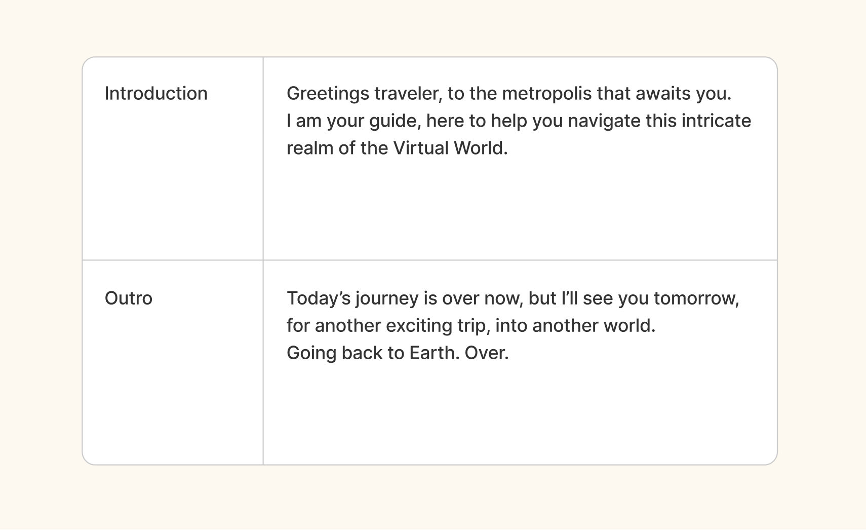
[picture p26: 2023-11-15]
presentations/concept-presentation-2023-11-16/Dossier_CdA_Concept_InDesign/Links/assistant_intro_outro.png

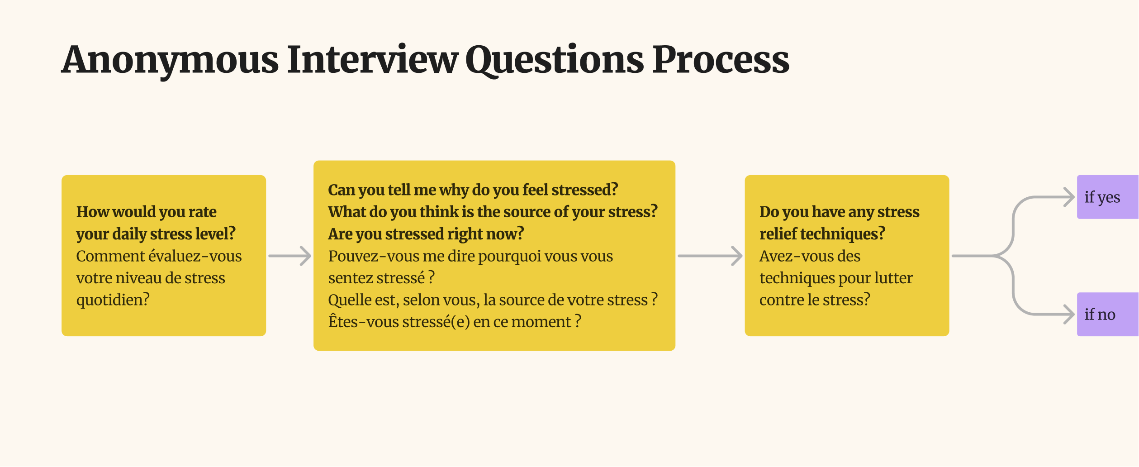
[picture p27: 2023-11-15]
presentations/concept-presentation-2023-11-16/Dossier_CdA_Concept_InDesign/Links/Screenshot 2023-11-15 121359.png

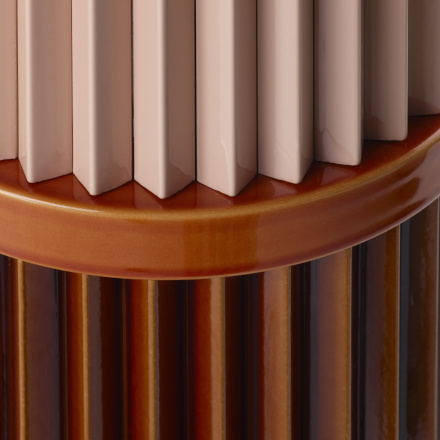
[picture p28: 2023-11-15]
presentations/concept-presentation-2023-11-16/Dossier_CdA_Concept_InDesign/Links/7838_n_02_B_Brun_rose_md.jpg

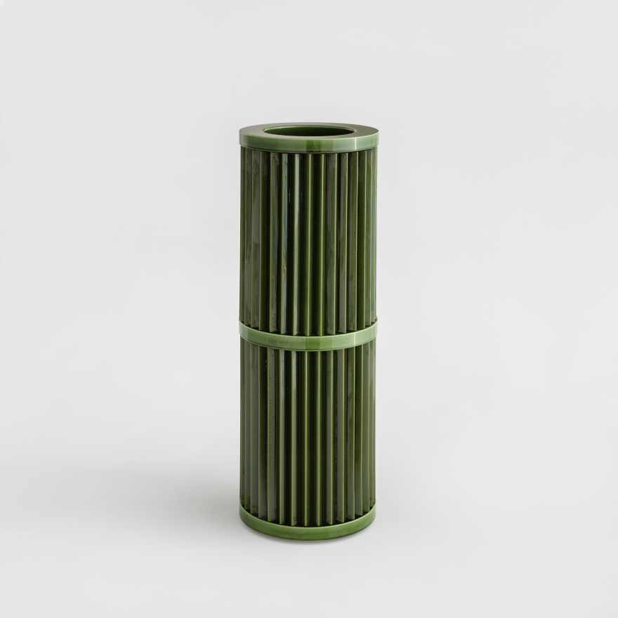
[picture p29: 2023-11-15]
presentations/concept-presentation-2023-11-16/Dossier_CdA_Concept_InDesign/Links/7725_z_vase_B_glossy_brun_matt-blue-6925_lg.png

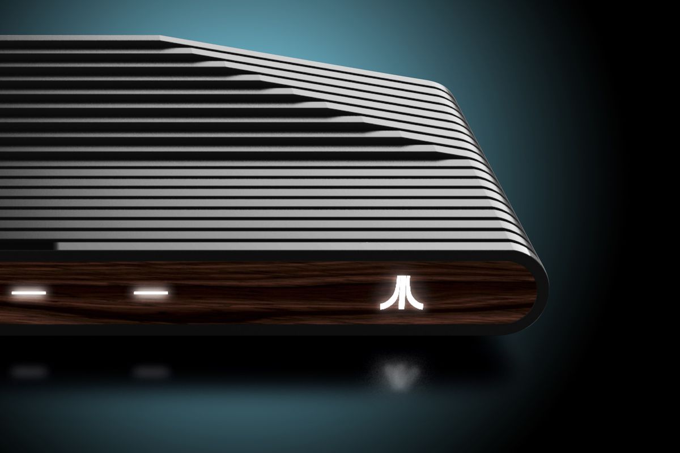
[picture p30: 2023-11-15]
presentations/concept-presentation-2023-11-16/Dossier_CdA_Concept_InDesign/Links/vcs_front.0.jpg

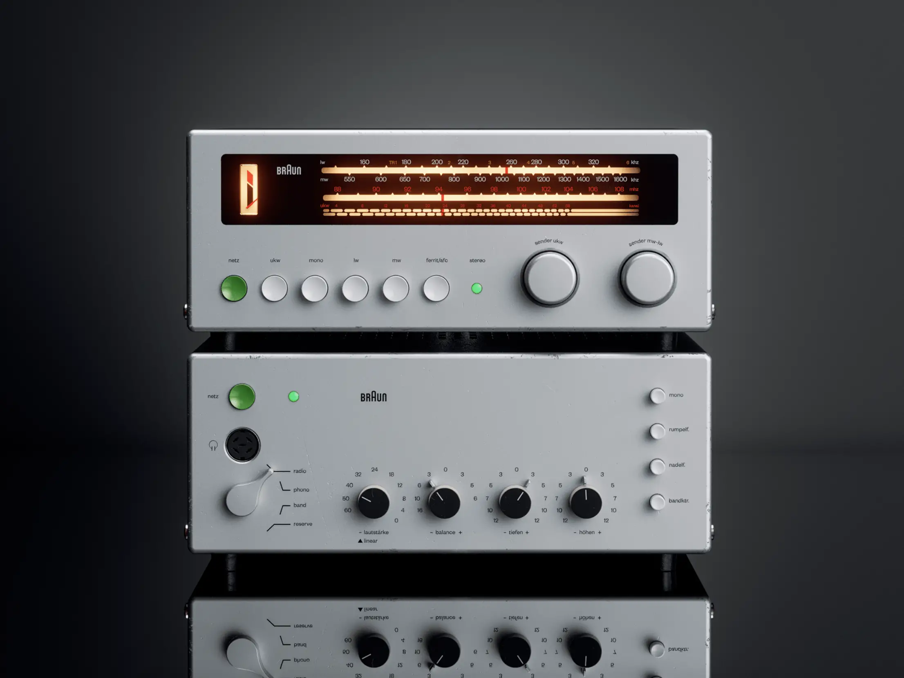
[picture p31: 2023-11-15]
presentations/concept-presentation-2023-11-16/Dossier_CdA_Concept_InDesign/Links/braun_radio.png

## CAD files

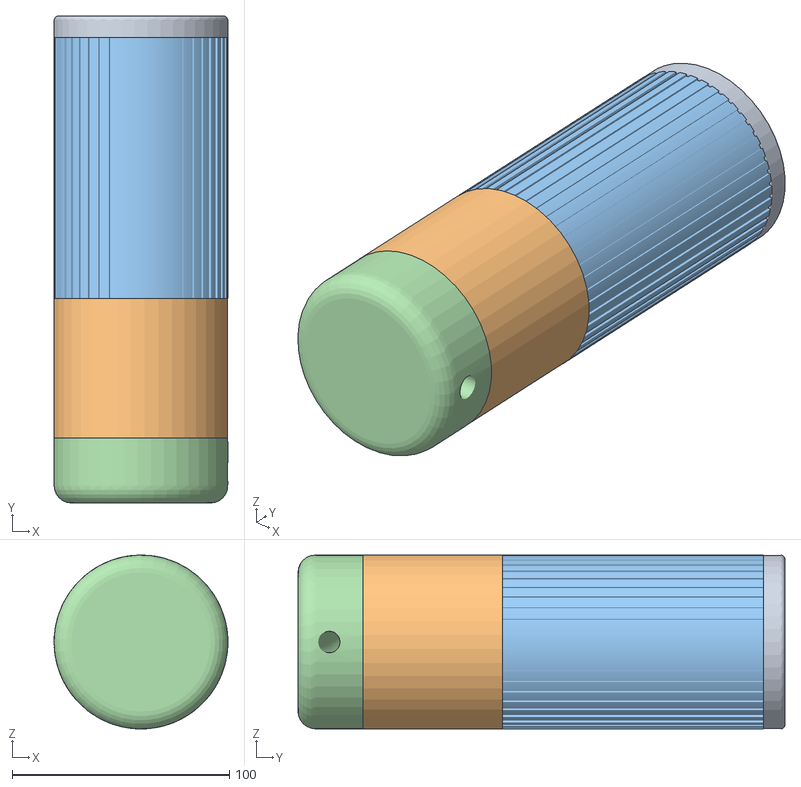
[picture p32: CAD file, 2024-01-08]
form/render/morpheus.obj
80.0 x 224.0 x 80.0
Top
Fabric Speaker Cover
Pen Holder
Base
Speaker Grill
Pen Press

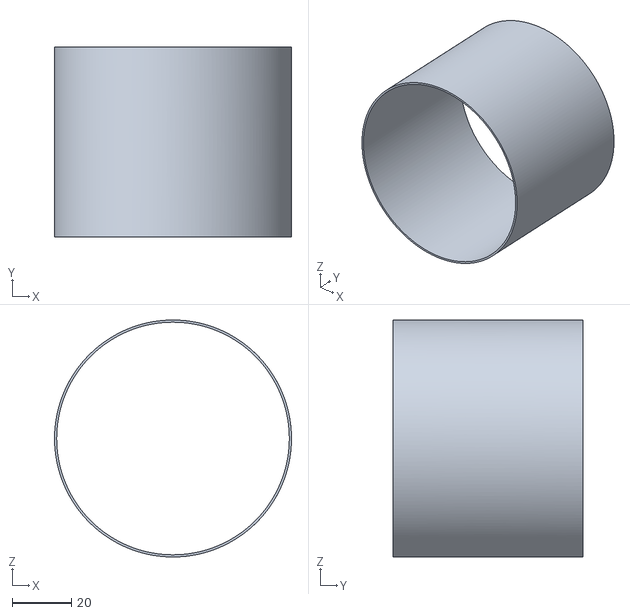
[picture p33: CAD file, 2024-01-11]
form/source/print/Fabric Speaker Cover.stl
80.0 x 64.0 x 80.0

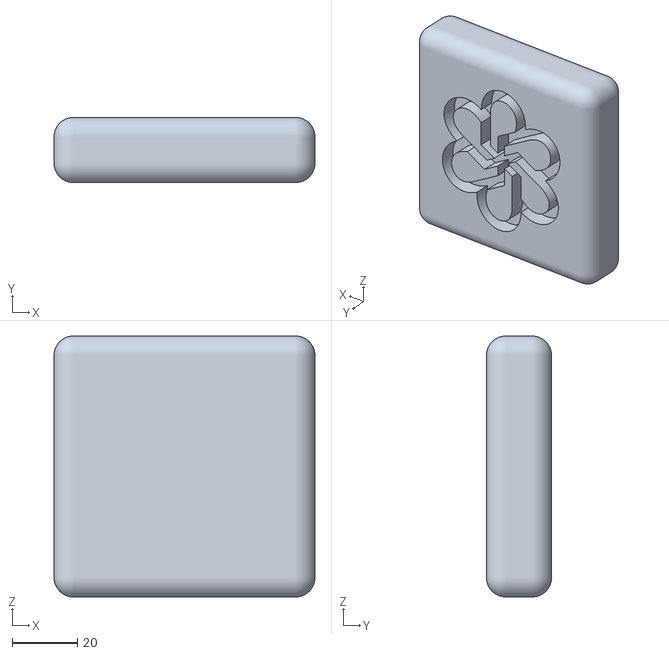
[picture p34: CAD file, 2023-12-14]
form/Tests/3dprint_test_Box.stl
80.0 x 20.0 x 80.0

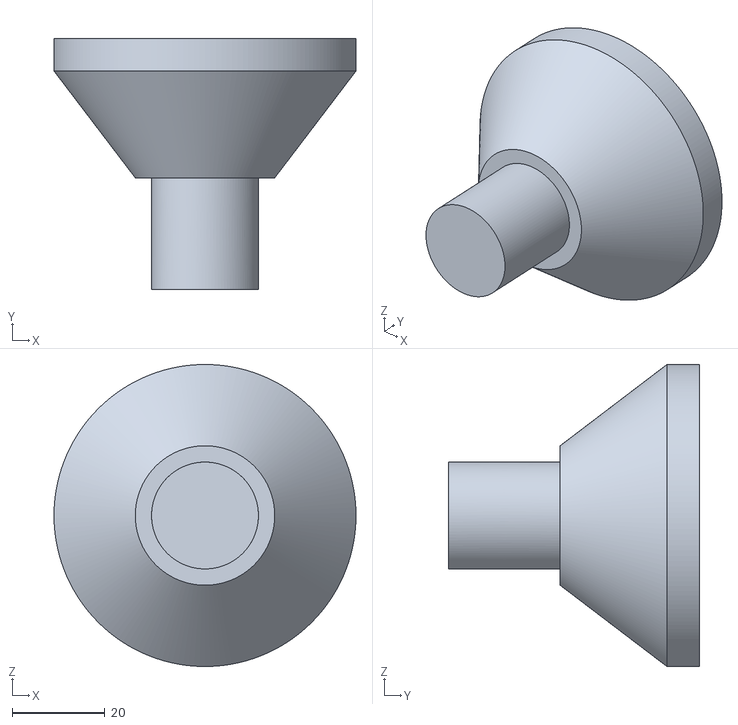
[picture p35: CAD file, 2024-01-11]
form/source/print/CdA_B_PenTrapDetector.stl
65.0 x 54.0 x 65.0

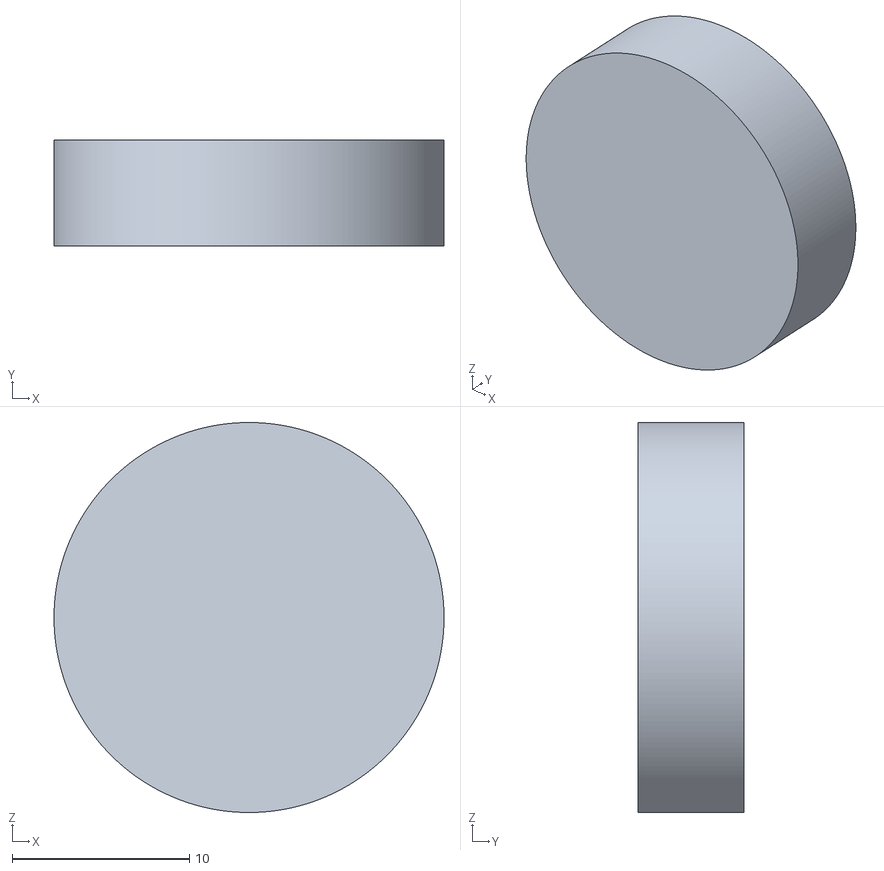
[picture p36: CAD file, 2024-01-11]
form/source/print/Supplement_to_PenTrap.stl
22.0 x 6.00 x 22.0

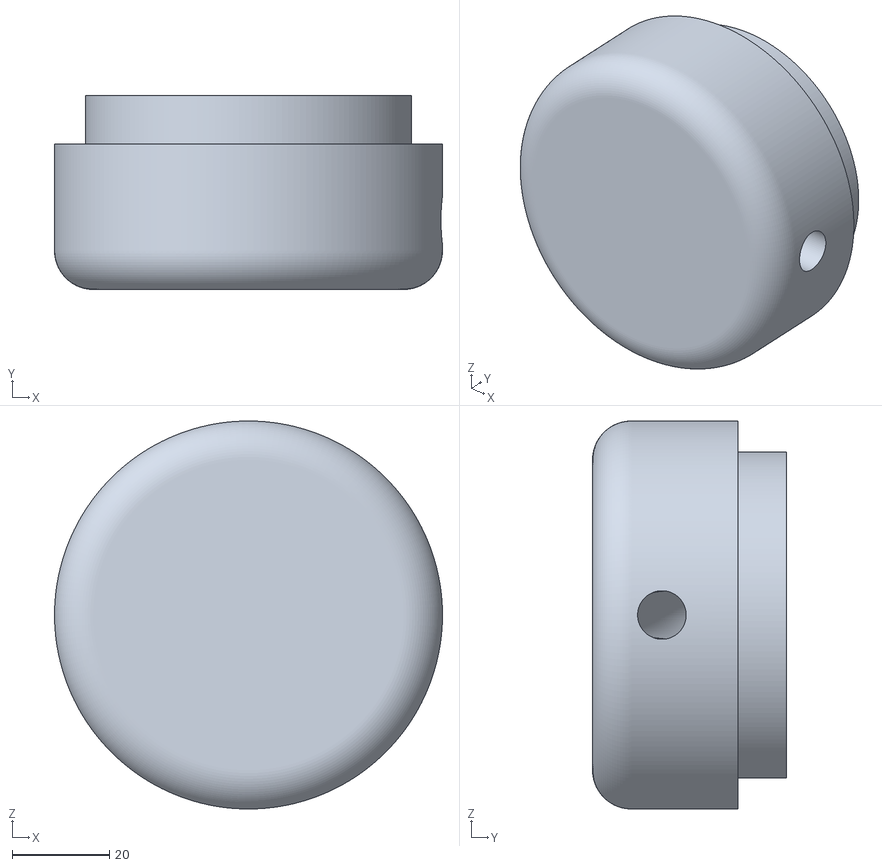
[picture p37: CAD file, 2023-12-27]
form/source/print/CdA_E_Base.stl
80.0 x 40.0 x 80.0

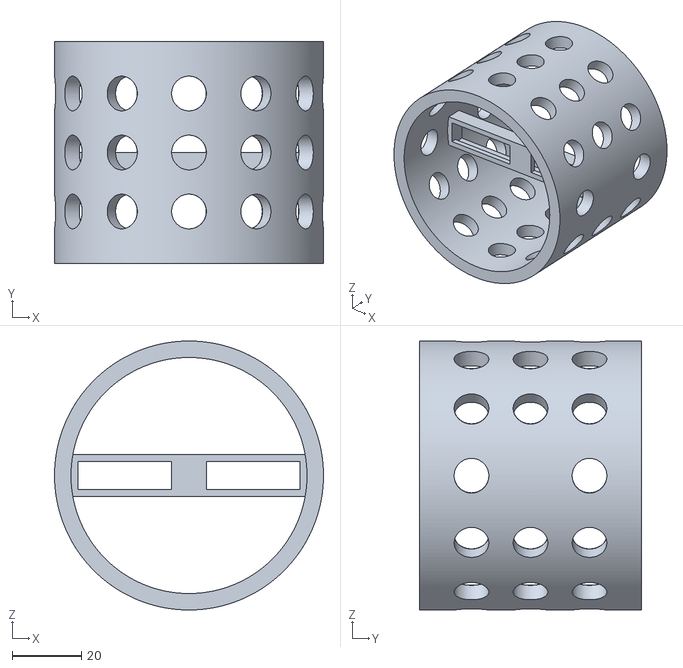
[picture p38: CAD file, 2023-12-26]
form/source/print/CdA_D_SpeakerGrill.stl
77.5 x 64.0 x 77.5

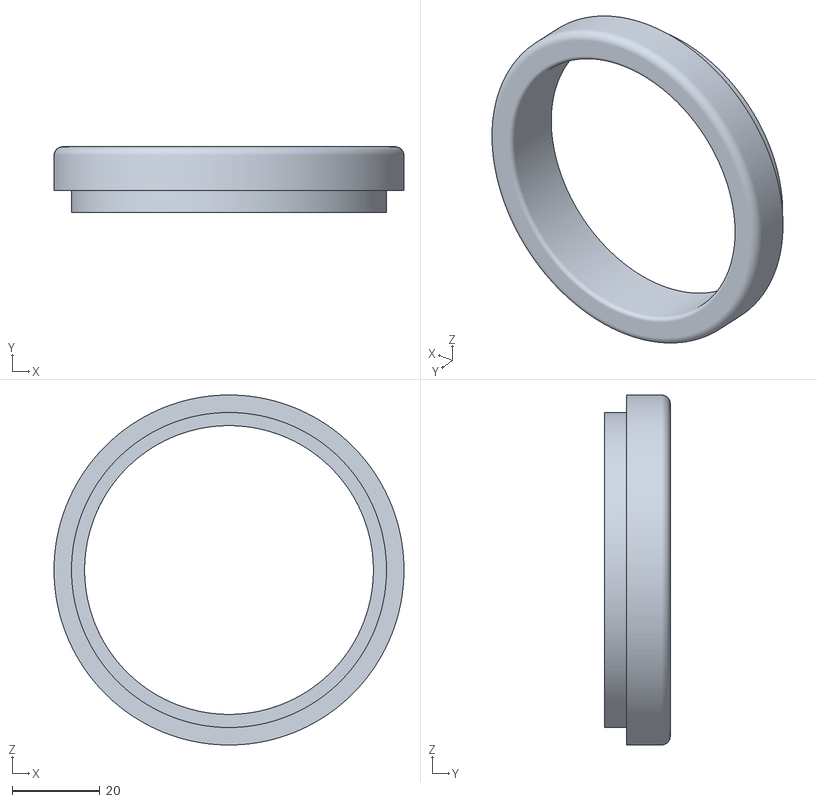
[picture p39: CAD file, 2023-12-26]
form/source/print/CdA_A_Top.stl
80.0 x 15.0 x 80.0

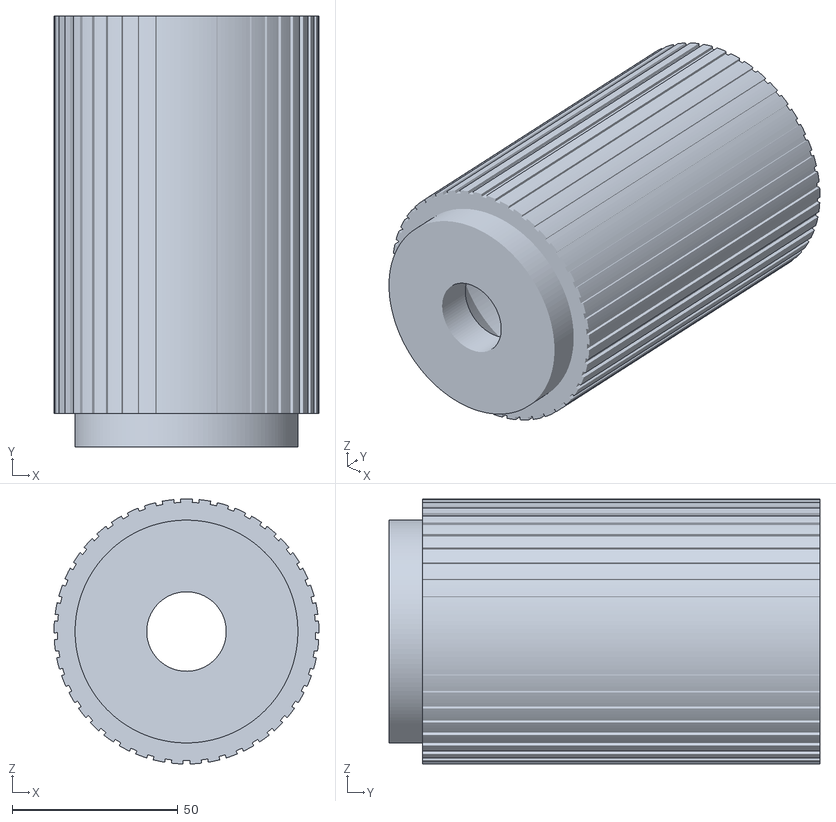
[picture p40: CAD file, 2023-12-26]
form/source/print/CdA_C_PenHolder.stl
80.0 x 130.0 x 80.0

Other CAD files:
form/source/AdamChatir_Morpheus.f3d
form/source/projectmorpheus_id.f3d

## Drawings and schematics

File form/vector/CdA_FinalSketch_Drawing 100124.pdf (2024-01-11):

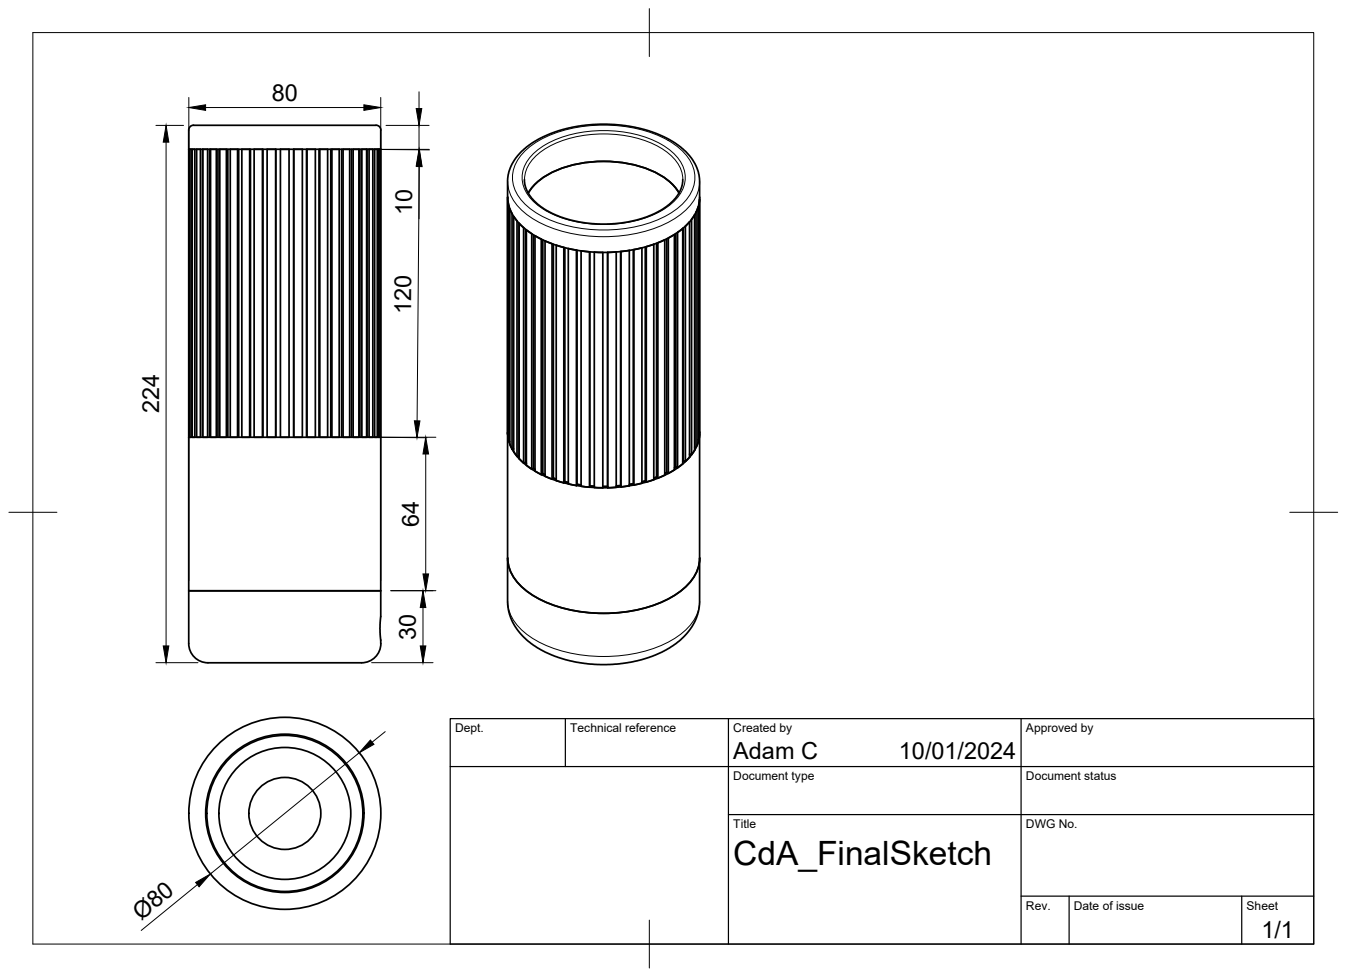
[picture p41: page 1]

Dept. | Technical reference | Created by Adam C 10/01/2024 | Approved by

Document type | Document status

Title CdA_FinalSketch | DWG No.

Rev. | Date of issue | Sheet 1/1

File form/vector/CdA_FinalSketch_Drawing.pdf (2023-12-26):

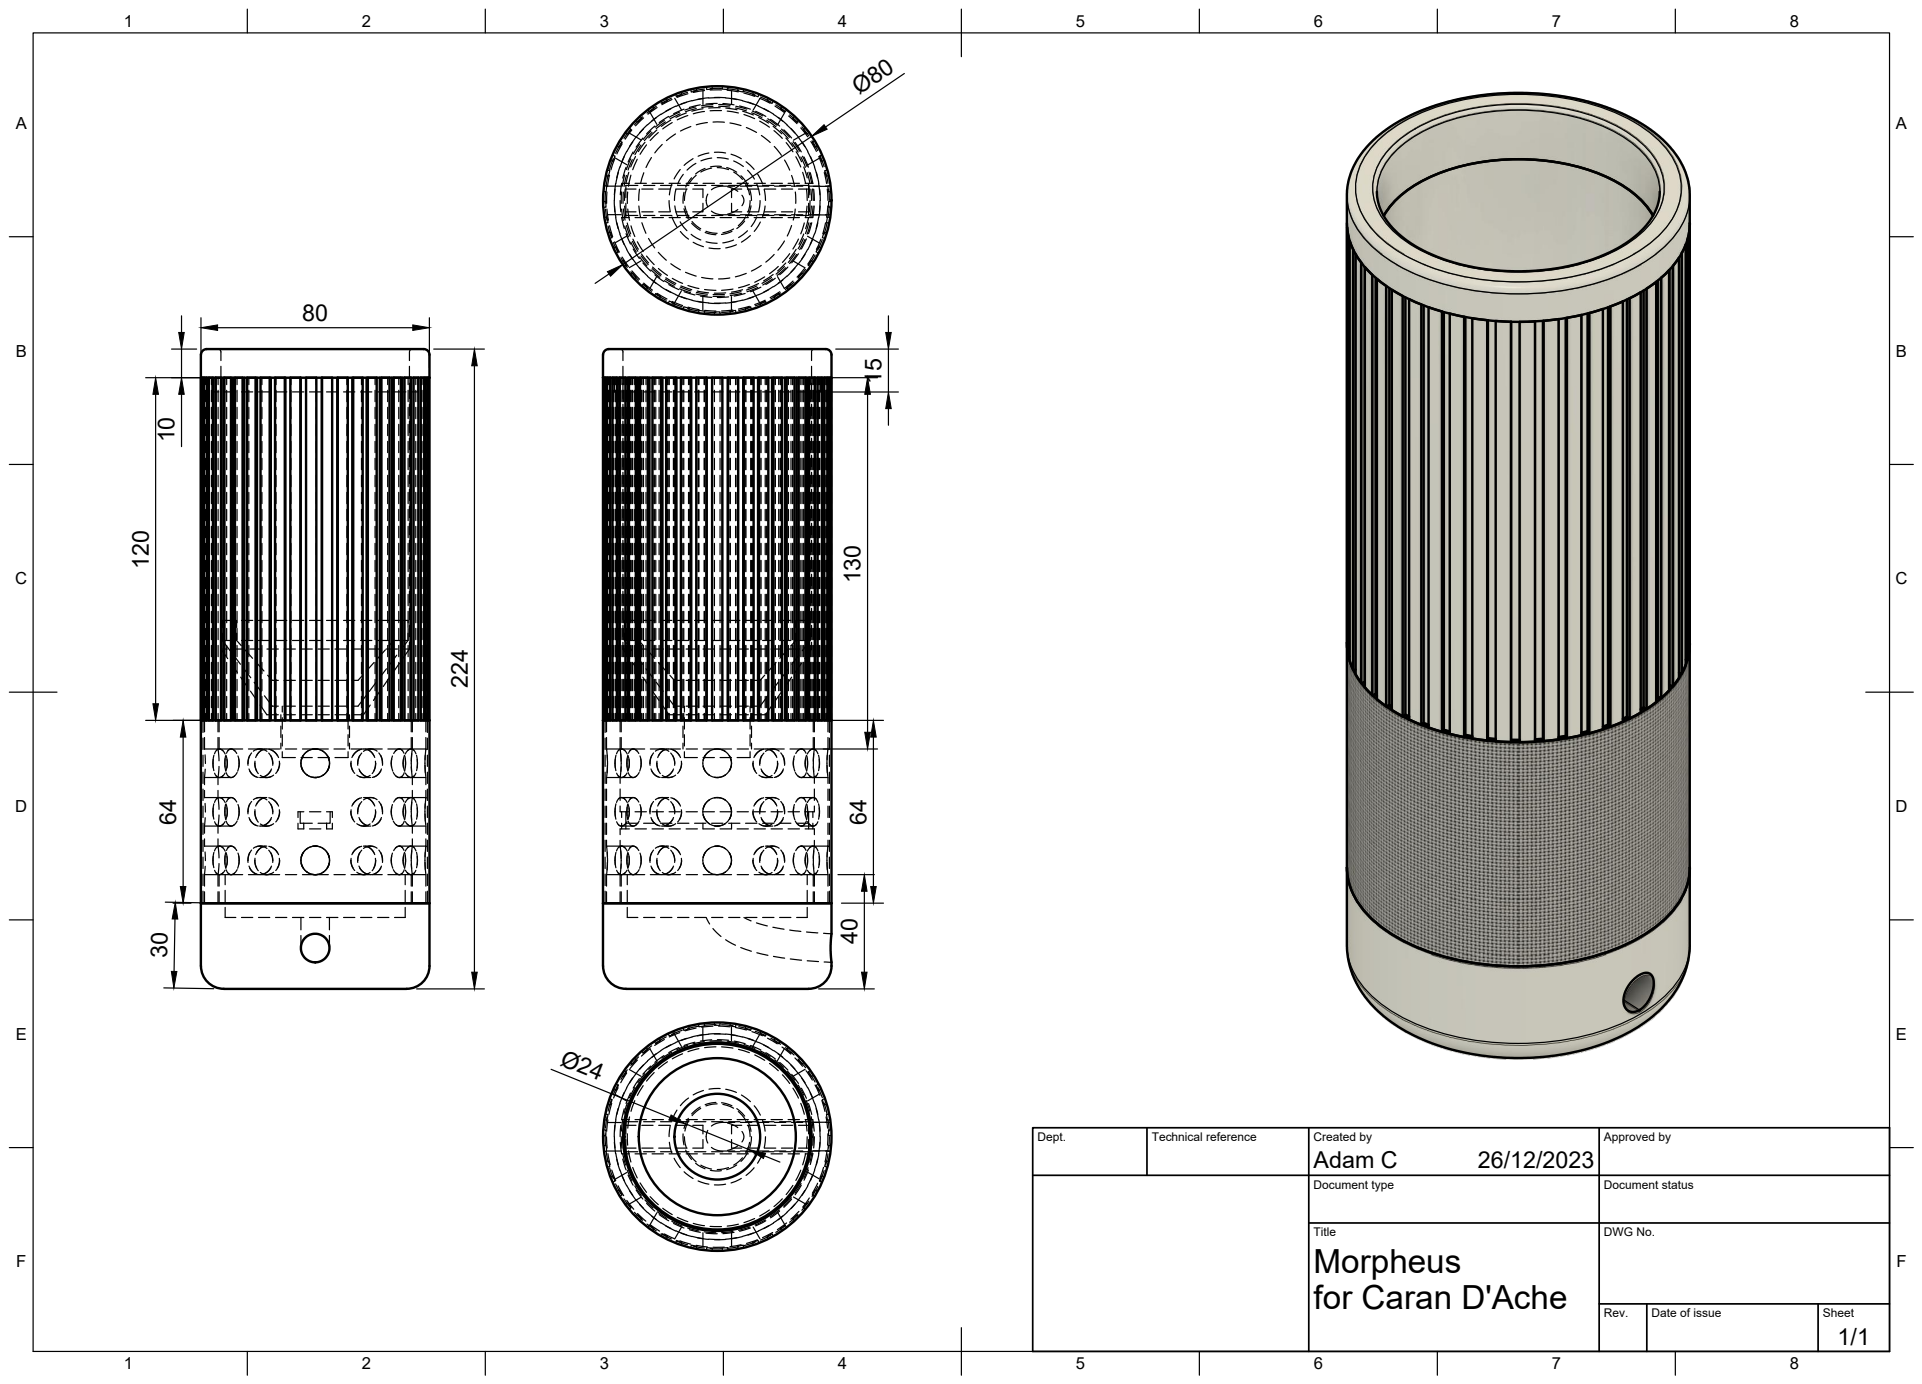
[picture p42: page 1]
Dept.; Technical reference; Created by; Approved by; Document type; Document status; Title; DWG No.; Rev.; Date of issue; Sheet; Adam C

Morpheus
for Caran D'Ache

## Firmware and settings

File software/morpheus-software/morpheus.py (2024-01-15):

# MORPHEUS SOFTWARE 0.1
# CYBRNEON SOFTWARE 2024

import RPi.GPIO as GPIO
import os
import vlc # VLC media player library
from time import sleep # to pause the script for a certain time

audio_folder = "/home/pi/Desktop/Morpheus/audio" # path to all audio files
audio_files = sorted([file for file in os.listdir(audio_folder) if file.endswith(".mp3")]) #List of mp3s in the audio folder

instance = vlc.Instance() # creating a VLC instance
media_list = instance.media_list_new([os.path.join(audio_folder, file) for file in audio_files]) #Creating a media list with all the mp3s in the audio folder
media_list_player = instance.media_list_player_new() # creating a media list player
media_list_player.set_media_list(media_list)

GPIO.setmode(GPIO.BCM) # set up BCM GPIO numbering
GPIO.setup(4, GPIO.IN, pull_up_down=GPIO.PUD_UP) # set GPIO4 as input (button) with a pull-up resistor

try:
    while True:
        if GPIO.input(4): # monitoring the GPIO pin 4 state
            print("GPIO 4 is 1/HIGH/True - Sound Playing")
            if not media_list_player.is_playing():
                media_list_player.play()
        else:
            print("GPIO 4 is 0/LOW/False - Sound Stopped")
            media_list_player.stop()
            sleep(0.1)

except KeyboardInterrupt: # stop the program with Ctrl + C
    pass

finally:
    GPIO.cleanup() # release all GPIO resources

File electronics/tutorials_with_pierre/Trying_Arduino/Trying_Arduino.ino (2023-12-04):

#define LED 13 //Define the constant
boolean val = HIGH; //Variable (needs a semicolon)

//Turns on the on-board LED
void setup()
{
  pinMode(LED, OUTPUT);
}

// the loop function runs over and over again forever
void loop()
{
  digitalWrite(LED, val);  // turn the LED on (HIGH is the voltage level)
  delay(1000);                      // wait for a second
  val = !val;
}

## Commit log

2023-11-13 added powerpoint for CdA Concept Presentation
2023-11-15 new prototypes pictures added
2023-11-15 added Pablo in root readme. Sorry Pablo 🫶
2023-12-04 Electronics and Arduino with Pierre
2023-12-12 today's progress
    [CdA_Test1_Base.stl, CdA_Test1_PenHolder.stl, CdA_Test1_Speaker.stl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]
2023-12-13 wednesday morning work
    [3d_Printing_Test2.stl]
2023-12-13 added 3d print photo
2023-12-14 git is malfunctionning, trying a fix
    [3d_Printing_Test2.stl, 3dprint_test_Box.stl, CdA_Test1_PenHolder.stl]
2023-12-18 finalized the Form page
    [projectmorpheus_id.f3d]
2023-12-20 fixed typo + changed hierarchy
    [CdA_Test1_Base.stl, CdA_Test1_PenHolder.stl, CdA_Test1_Speaker.stl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]
2023-12-26 Updated Form with Laure's corrections.
    [CdA_A_Top.stl, CdA_B_PenTrapDetector.stl, CdA_C_PenHolder.stl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]
2023-12-27 Updated Fusion file and STLs with minor change to the base.
    [CdA_E_Base.stl, projectmorpheus_id.f3d]
2024-01-08 added FBX and OBJ
    [morpheus.obj]
2024-01-11 Small updates + prep for final presentation
    [AdamChatir_Morpheus.f3d, CdA_B_PenTrapDetector.stl, Fabric Speaker Cover.stl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]
2024-01-15 cut the story into different segments
